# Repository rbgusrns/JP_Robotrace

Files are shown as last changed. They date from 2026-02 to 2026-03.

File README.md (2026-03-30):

<div align="center">

# JP_Robotrace
### Competition-grade line tracing robot platform

A complete robot tracing project that brings together firmware, electronics, and mechanical design in one repository.

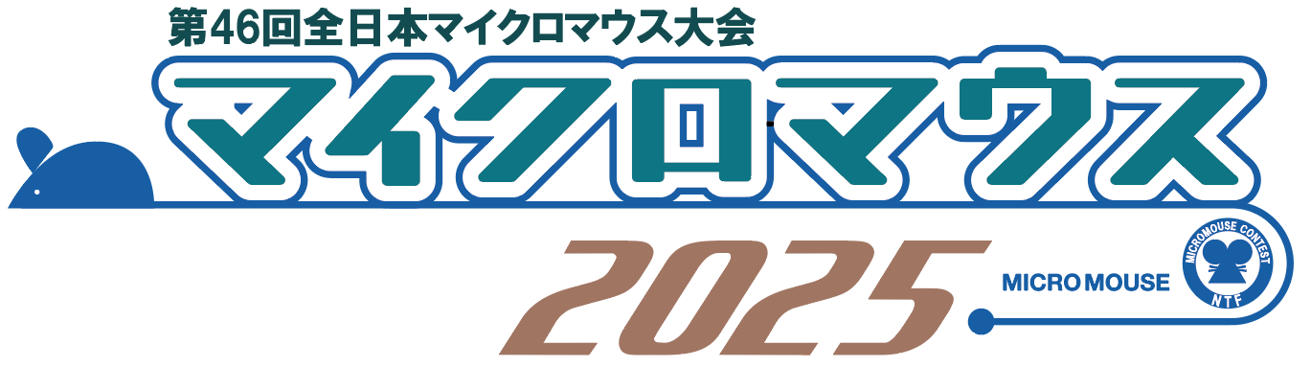
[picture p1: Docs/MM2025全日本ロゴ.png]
MM2025 poster


<br />






</div>

---

## Overview

`JP_Robotrace` is a line tracing robot project built for high-speed autonomous racing. The repository does not only contain firmware. It also includes PCB design data, manufacturing outputs, mechanical assets, and component references, which makes it closer to a full robot platform archive than a source-only codebase.

At the center of the project is a TI C2000-based control system tuned for fast and stable line following, with dedicated run modes, sensor processing, motion control, and board-level hardware design captured together in one place.

---

## Competition Result

`JP_Robotrace` competed as `RT51` at MM2025 and finished in 8th place overall.

The official best record captured in the event result sheet is `0:13.074`, which makes this repository not just a development archive, but also a record of a robot that completed the competition with a top-10 finish.

<p align="center">
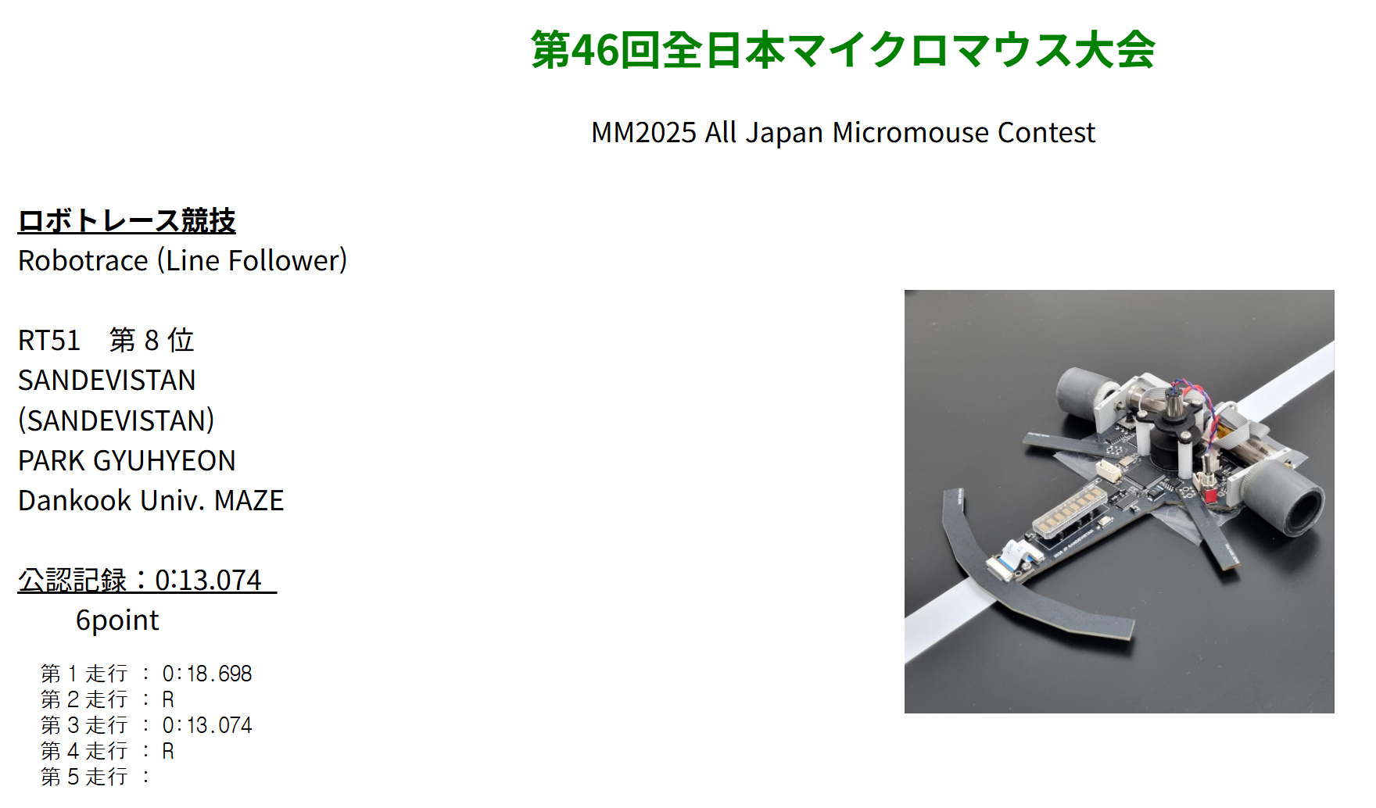
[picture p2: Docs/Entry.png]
MM2025 result sheet showing RT51 finishing 8th
  
</p>

<p align="center">
  <sub>MM2025 result sheet for RT51: finished 8th with an official best record of 0:13.074.</sub>
</p>

---

## Gallery

<table>
  <tr>
    <td width="50%">
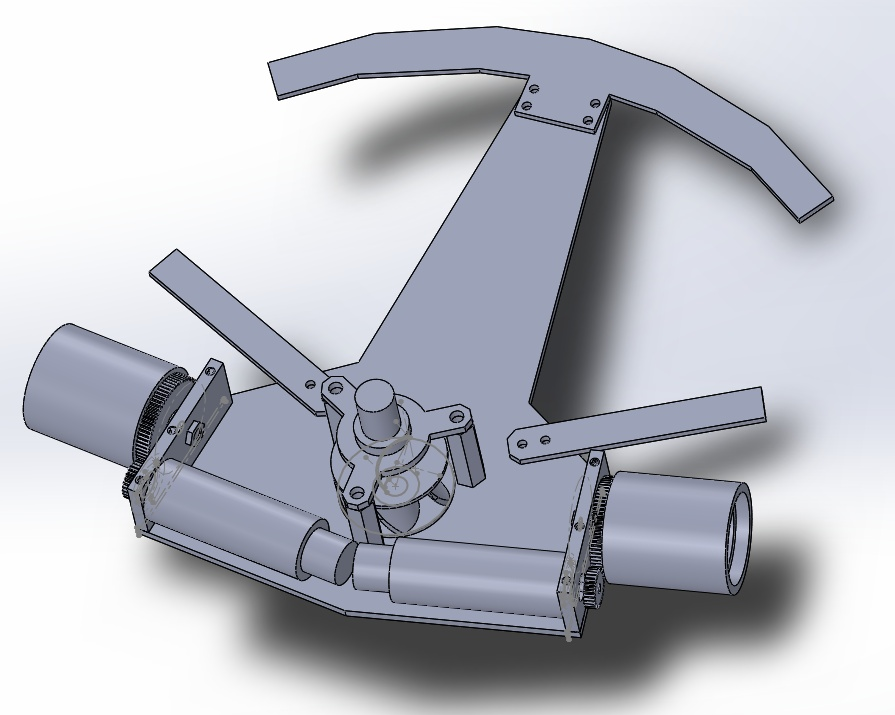
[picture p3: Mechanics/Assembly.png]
Assembly model
      
    </td>
    <td width="50%">
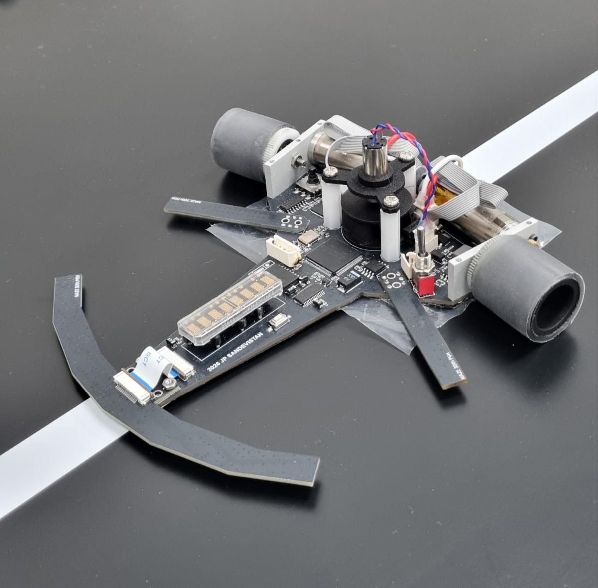
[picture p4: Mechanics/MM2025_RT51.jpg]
Robot photo
      
    </td>
  </tr>
  <tr>
    <td width="50%">
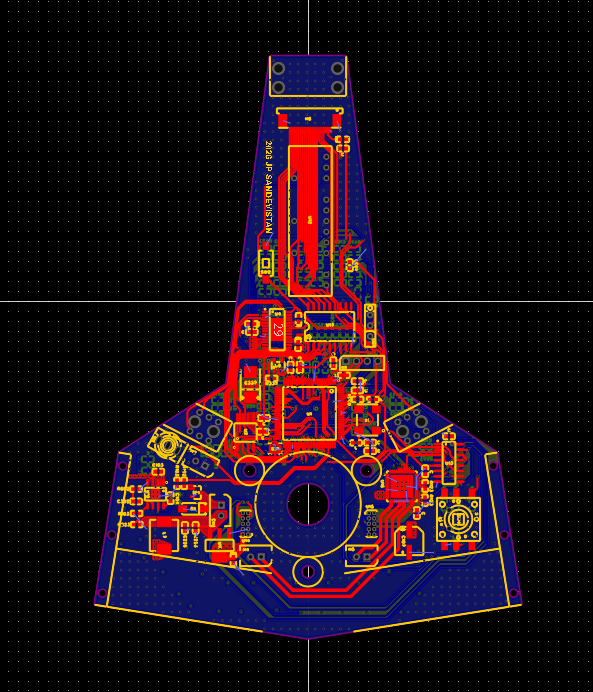
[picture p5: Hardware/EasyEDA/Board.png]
Main board
      
    </td>
    <td width="50%">
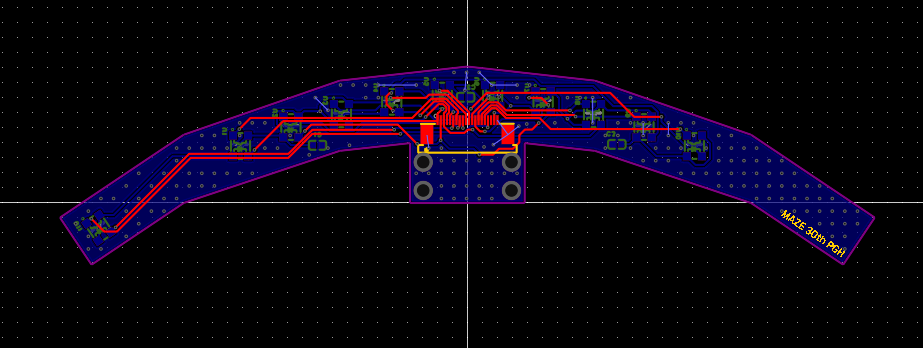
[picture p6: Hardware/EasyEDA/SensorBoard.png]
Sensor board
      
    </td>
  </tr>
</table>

<p align="center">
  <sub>Event identity, mechanical design, real hardware, and board-level engineering all live in the same archive.</sub>
</p>

---

## Key Features

- High-speed line tracing firmware for competitive robot racing
- Multiple driving modes including search, fast run, extreme run, and bril run
- Closed-loop motion control using encoder and sensor feedback
- Dedicated modules for motor control, gyro handling, flash, menu, and display
- Hardware resources including EasyEDA projects and production Gerber files
- Mechanical assets including STEP models and assembled robot visuals

---

## Project Structure

```text
JP_Robotrace/
├── Docs/                    # Component documents and technical references
├── Hardware/                # PCB design files, Gerbers, and logic references
│   ├── EasyEDA/
│   ├── Gerber/
│   └── Logic/
├── Mechanics/               # Mechanical assets, photos, and STEP models
│   └── STEP/
└── Software/                # Embedded firmware source and toolchain files
    ├── Compiler/
    ├── include/
    └── main/
```

---

## Software Layout

The embedded source is centered in `Software/main/`, where the project is split by function instead of by abstraction-heavy layers. Important files include:

- `main.c` - system initialization and core runtime setup
- `Motor.c` - motor control logic
- `Sensor.c` - sensor processing for line detection
- `gyro.c` - gyro interface and related handling
- `Search.c` - search-oriented run logic
- `Fastrun.c` - faster race mode logic
- `Extremerun.c` - aggressive run profile
- `brilrun.c` - high-performance run mode
- `Menu.c` - local interface and configuration flow
- `flash.c` - flash memory handling
- `VFD.c` - display output control

The source was written with Source Insight as the editing environment, and the shipped `Software/main/MAKEFILE` identifies the output target as `a_ZILLIIAX` while referencing a TI C2000-oriented IAR build chain and supporting libraries.

---

## Hardware

This repository also preserves the electrical side of the robot.

- `Hardware/EasyEDA/` contains editable PCB project files and preview images
- `Hardware/Gerber/` contains manufacturing-ready archives for the boards
- `Hardware/Logic/` contains supporting circuit reference documents

---

## Mechanical Assets

The `Mechanics/` directory includes both presentation assets and 3D geometry.

- `Assembly.png` shows the assembled system
- `MM2025_RT51.jpg` captures the robot in a real-world setting
- `STEP/` stores mechanical models such as wheel, gear, tire, and assembly data

That combination makes the repository useful not only for firmware study, but also for reconstructing the full build context of the robot.

---

## Technology Snapshot

| Category | Details |
|---|---|
| MCU | Texas Instruments `TMS320F2808` |
| Firmware Language | `C`, `Assembly` |
| Editor | Source Insight |
| Build Configuration | TI C2000 / IAR-oriented make flow |
| Build Target | `a_ZILLIIAX` |
| Repository Scope | Firmware, PCB, Gerber, STEP, reference docs |

---

## Run Modes

Based on the source layout, the project includes several driving strategies with separate implementations:

- **Search** for controlled exploration and line acquisition
- **Fast Run** for higher-speed tracing
- **Extreme Run** for more aggressive motion profiles
- **Bril Run** for a top-end performance-oriented mode

This mode separation suggests a workflow that balances stability, route understanding, and maximum race pace.

---

## Build Notes

The repository contains source and make configuration, but it does not yet provide a polished step-by-step setup guide.

What can be verified from the repository:

- The firmware is built around a TI C2000 target
- The codebase was written with Source Insight as the editing environment
- `Software/main/MAKEFILE` references the IAR C2000 compiler, assembler, and linker
- The output target name is `a_ZILLIIAX`

What is still undocumented:

- Exact flashing procedure
- Required debugger or programmer hardware
- Board assembly and bring-up sequence
- Parameter tuning procedure for different tracks

---

## Why This Repository Is Interesting

Many robot repositories show only one slice of the work. `JP_Robotrace` is interesting because it keeps the full engineering story together: embedded control, electronics, manufacturing data, and mechanical design.

For anyone studying line tracing robots, embedded control systems, or complete competition robot workflows, this repository is a compact snapshot of how those disciplines come together in practice.

---

## Credits

From the project make configuration:

- **Author:** Yuk Keun Ho
- **Company:** MAZE

---

## License

This project is released under the `MIT` License. See `LICENSE` for details.

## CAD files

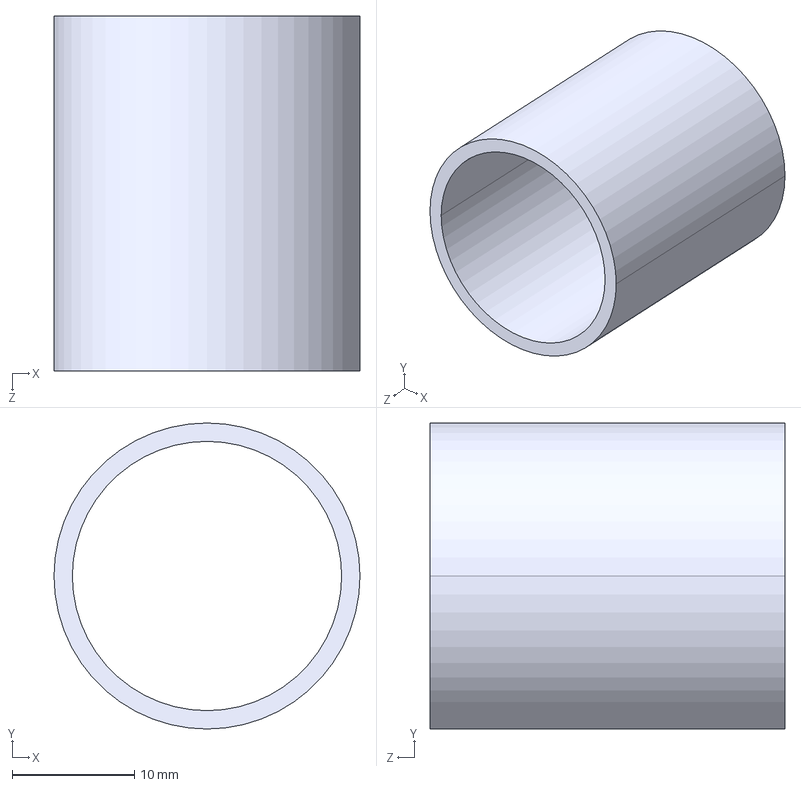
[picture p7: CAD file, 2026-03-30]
Mechanics/STEP/TIRE_OUT.STEP
25.0 x 25.0 x 29.0 mm

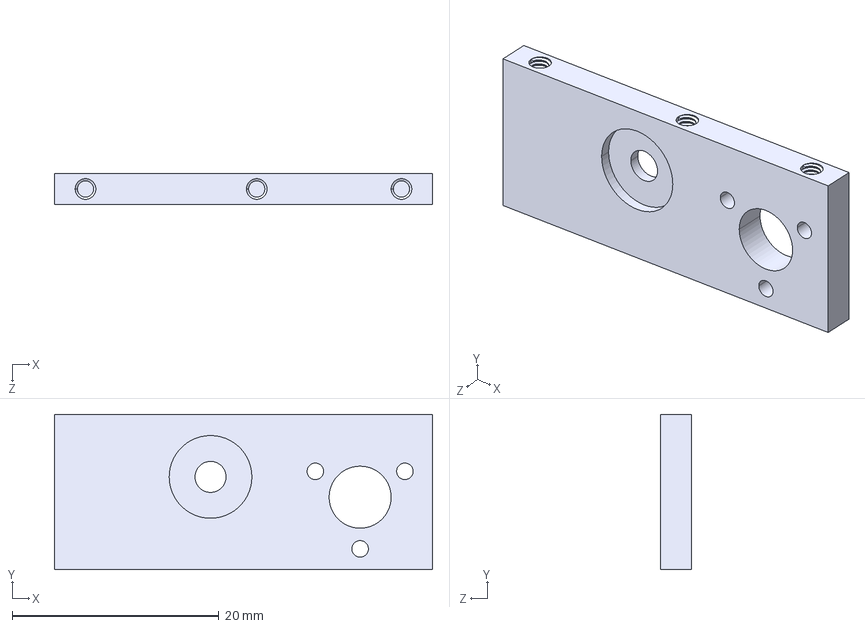
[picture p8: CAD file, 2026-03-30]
Mechanics/STEP/MTG_L.STEP
36.6 x 15.0 x 3.00 mm

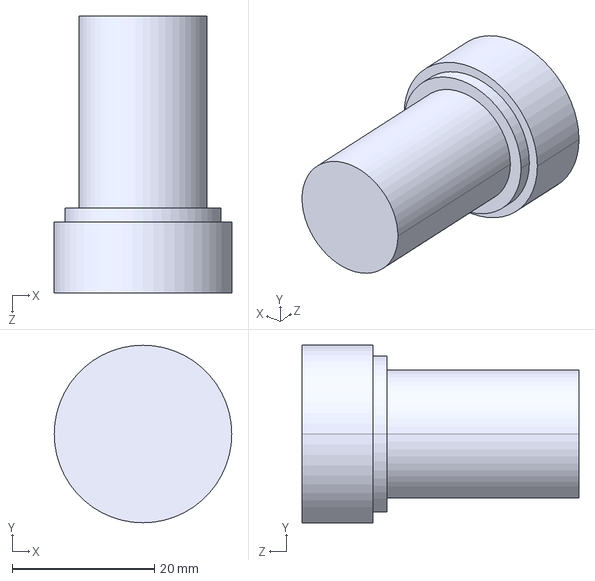
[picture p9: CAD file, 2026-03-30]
Mechanics/STEP/TIRE_IN.STEP
25.0 x 25.0 x 39.0 mm

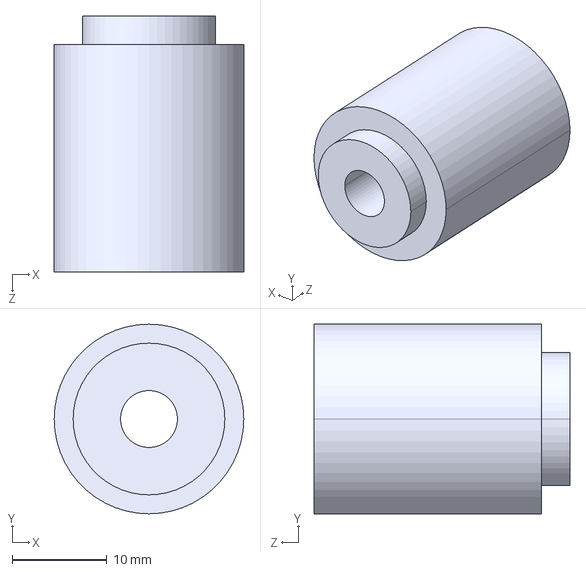
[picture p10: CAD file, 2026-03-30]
Mechanics/STEP/WHEEL.STEP
20.0 x 20.0 x 27.0 mm

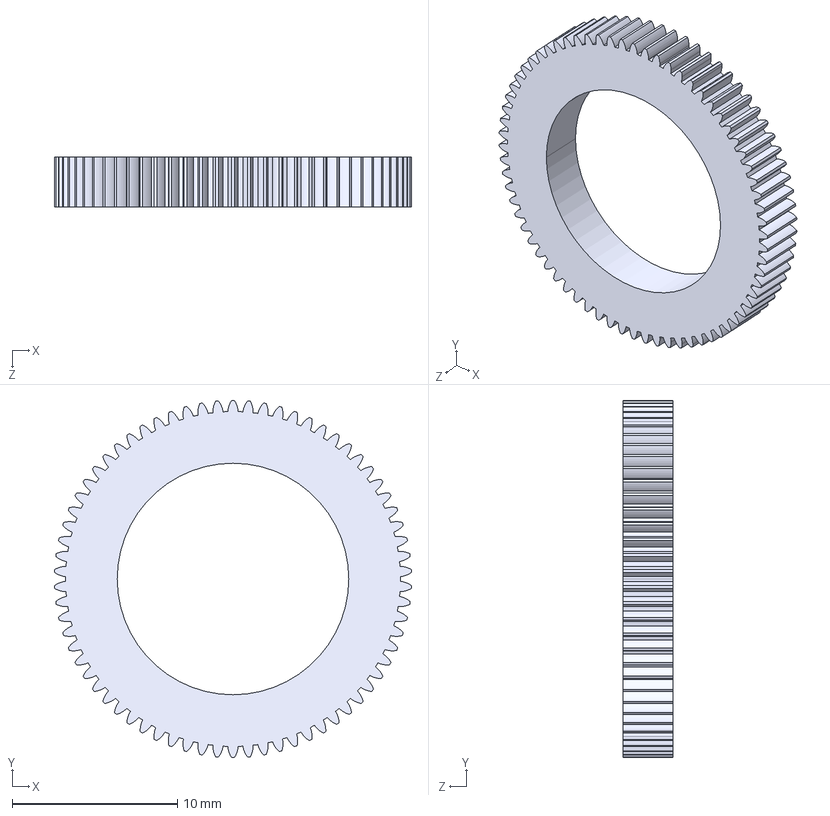
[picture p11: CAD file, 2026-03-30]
Mechanics/STEP/GEAR.STEP
21.6 x 21.6 x 3.00 mm

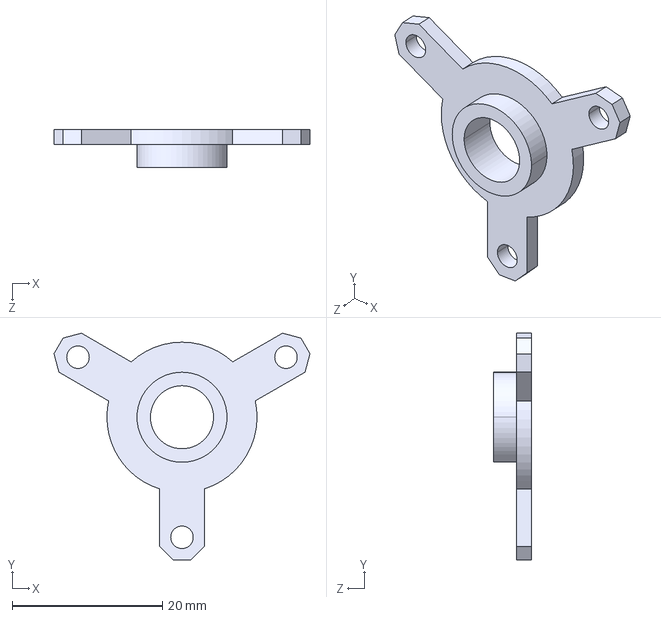
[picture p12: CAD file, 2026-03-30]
Mechanics/STEP/SUCTION_FIX.STEP
34.1 x 30.2 x 5.00 mm

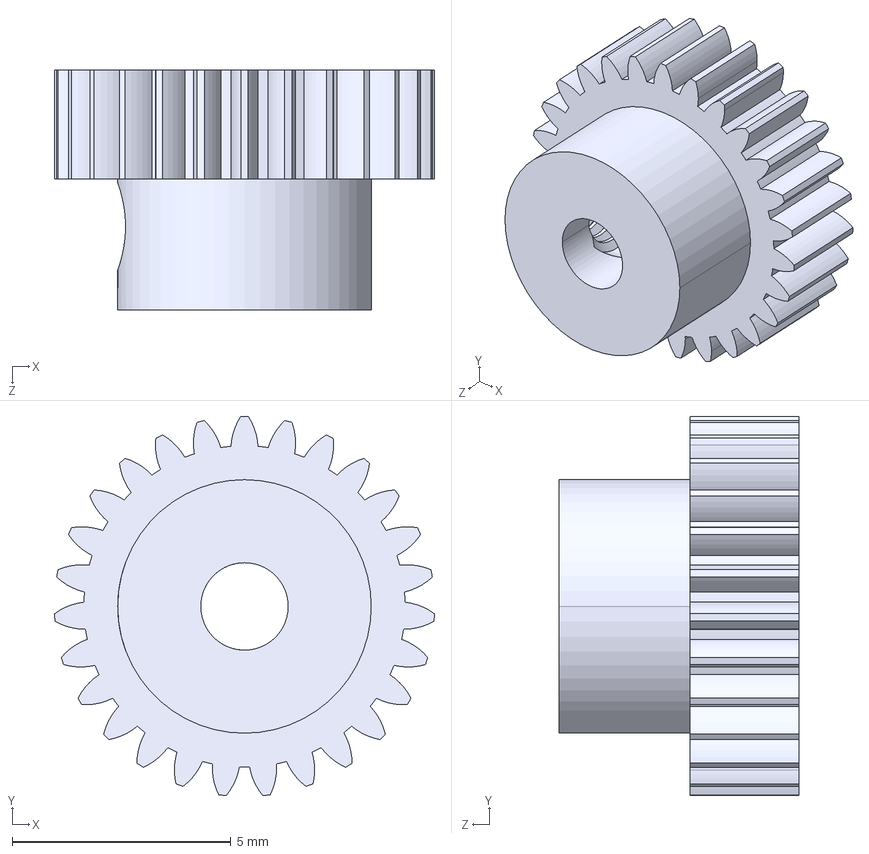
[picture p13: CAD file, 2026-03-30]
Mechanics/STEP/PINION.STEP
8.69 x 8.68 x 5.50 mm

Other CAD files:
Software/main/main.obj
Software/main/Rom.obj
Software/main/DSP280x_DefaultIsr.obj
Mechanics/STEP/JP_MTG_R.STEP
Software/main/DSP280x_EPwm.obj
Software/main/VFD.obj
Software/main/sensor.obj
Mechanics/STEP/JP_MTG_L.STEP
Software/main/DSP280x_PieCtrl.obj
Software/main/DSP280x_Gpio.obj
Software/main/fastrun.obj
Mechanics/STEP/MTG_R.STEP
Mechanics/STEP/SUCTION.STEP
Software/main/DSP280x_Adc.obj
Software/main/DSP280x_CodeStartBranch.obj
Software/main/DSP280x_CpuTimers.obj
Software/main/DSP280x_EQep.obj
Software/main/DSP280x_GlobalVariableDefs.obj
Software/main/DSP280x_MemCopy.obj
Software/main/DSP280x_PieVect.obj
Software/main/DSP280x_Sci.obj
Software/main/DSP280x_Spi.obj
Software/main/DSP280x_SysCtrl.obj
Software/main/DSP280x_usDelay.obj
Software/main/Motor.obj
Software/main/brilrun.obj
Software/main/extremerun.obj
Software/main/gyro.obj
Software/main/menu.obj
Software/main/search.obj

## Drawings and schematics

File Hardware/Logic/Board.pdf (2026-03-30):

GPIO4/EPWM3A 51 GPIO17/SPISOMIA/CANRXB/TZ6# 52 GPIO5/EPWM3B/SPICLKD/ECAP1 53 GPIO18/SPICLKA/SCITXDB 54 VSS 55 GPIO6/EPWM4A/EPWMSYNCI/EPWMSYNCO 56 GPIO19/SPISTEA/SCIRXDB 57 GPIO7/EPWM4B/SPISTED/ECAP2 58 VDD 59 GPIO8/EPWM5A/CANTXB/ADCSOCAO# 60 GPIO9/EPWM5B/SCITXDB/ECAP3 61 VSS 62 GPIO20/EQEP1A/SPISIMOC/CANTXB 63 GPIO10/EPWM6A/CANRXB/ADCSOCBO# 64 VDDIO 65 XCLKOUT 66 GPIO21/EQEP1B/SPISOMIC/CANRXB 67 VDD 68 VSS 69 GPIO11/EPWM6B/SCIRXDB/ECAP4 70 GPIO22/EQEP1S/SPICLKC/SCITXDB 71 GPIO23/EQEP1I/SPISTEC/SCIRXDB 72 TDI 73 TMS 74 TCK 75 TDO ⁷⁶ VSS ⁷⁷ XRS# 78 GPIO²⁷/ECAP⁴/EQEP²S/SPISTEB ⁷⁹ EMU⁰ ⁸⁰ EMU¹ ⁸¹ VDDIO ⁸² GPIO²⁴/ECAP¹/EQEP²A/SPISIMOB ⁸³ TRST# 84 VDD ⁸⁵

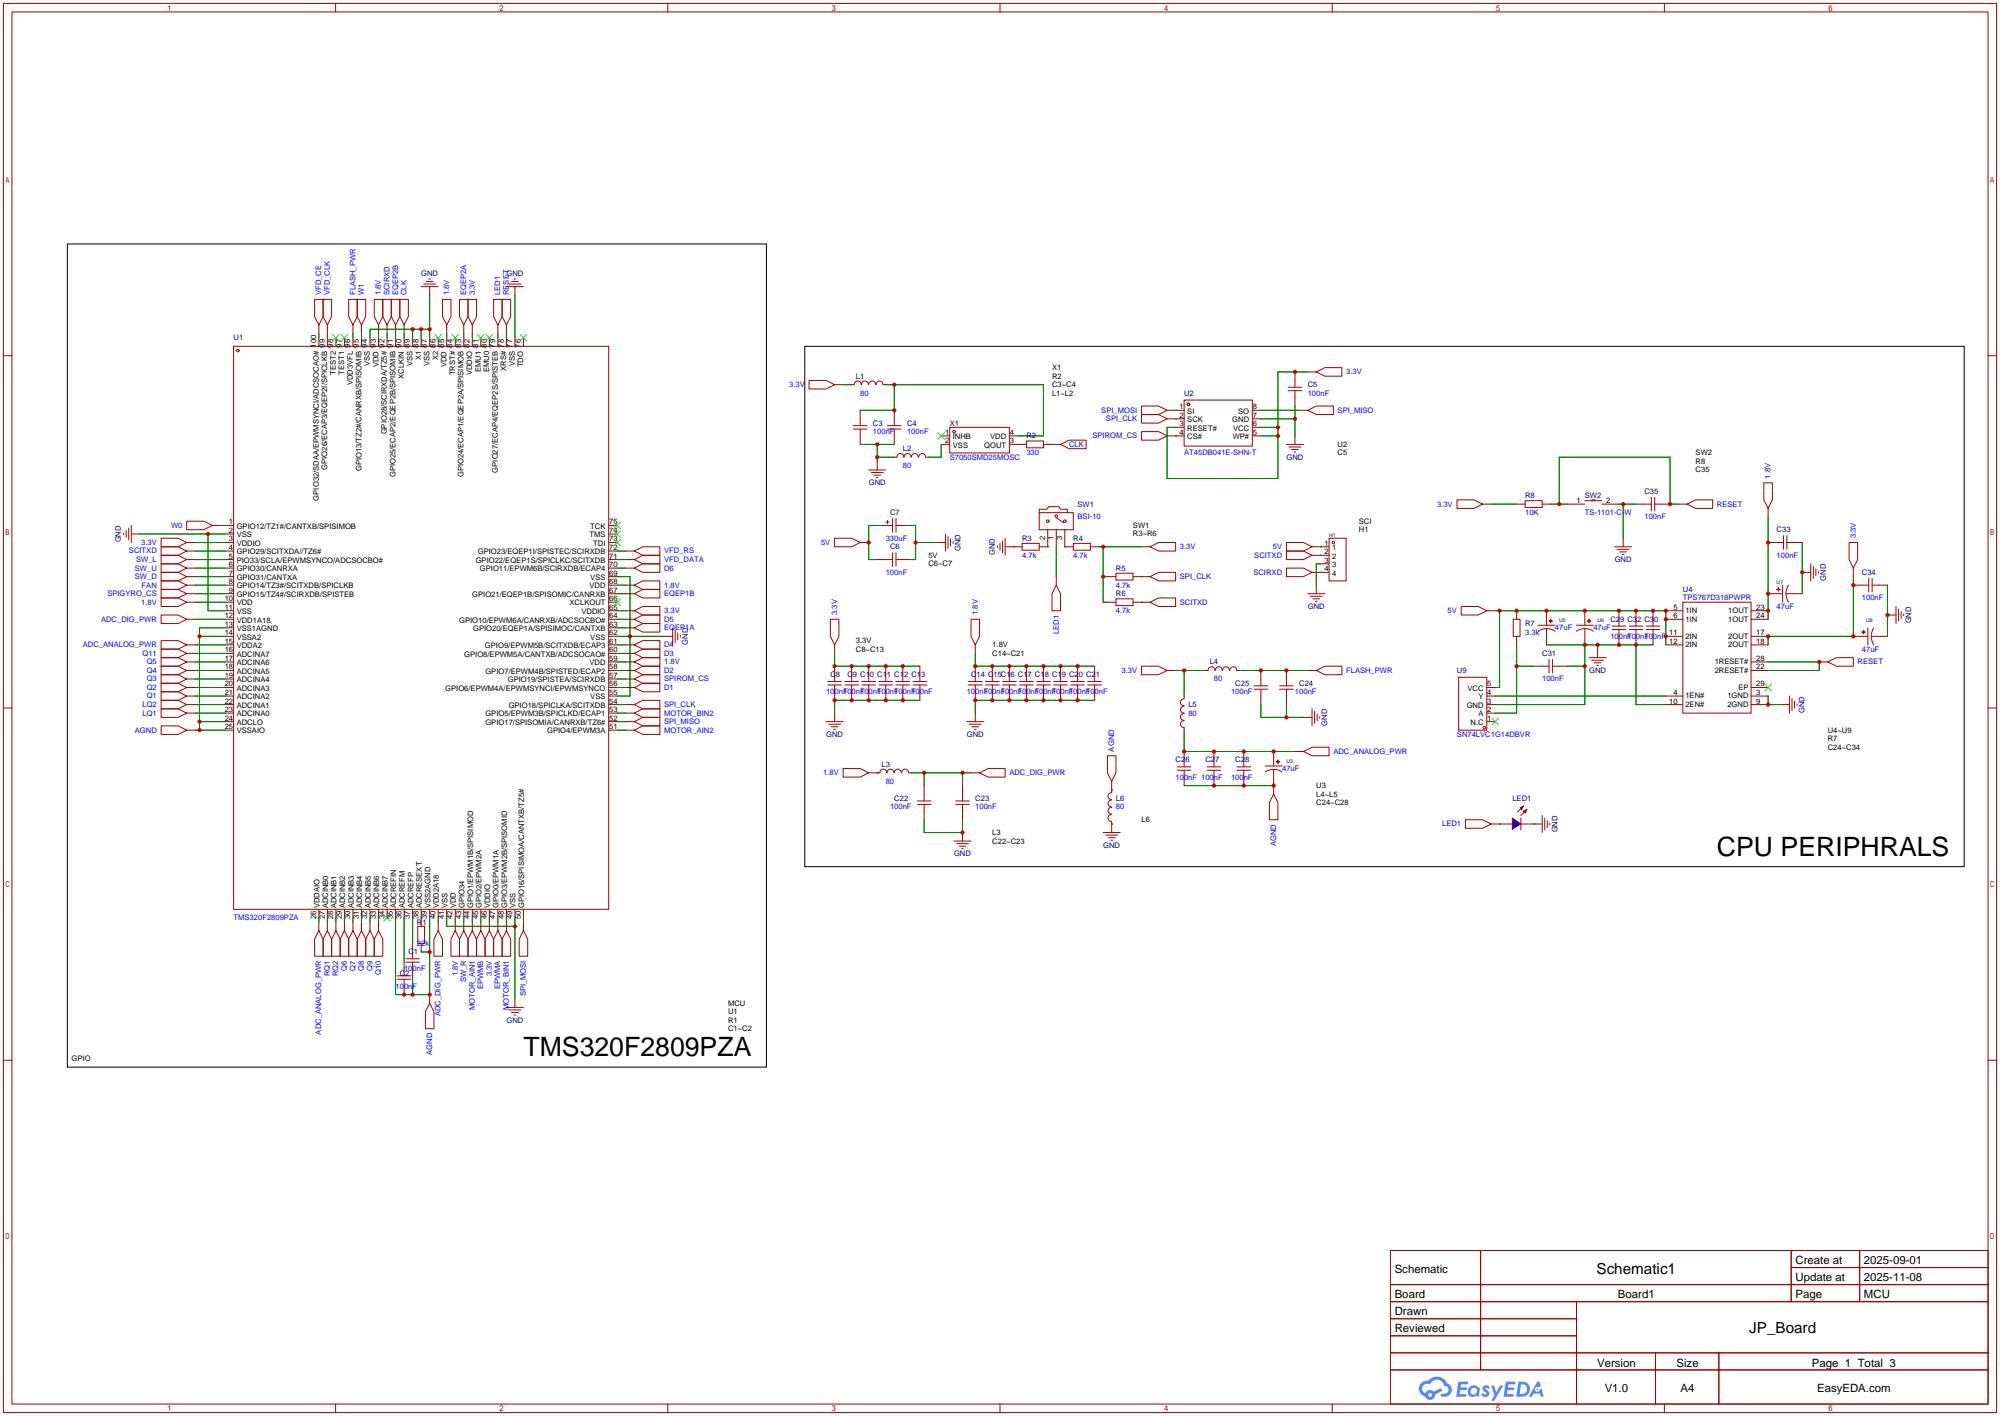
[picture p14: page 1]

Schematic | Schematic1 | Create at | 2025-09-01

Update at | 2025-11-08

Board | Board1 | Page | MCU
Drawn | | JP_Board
Reviewed

Version | Size | Page 1 Total 3
V1.0 | A4 | EasyEDA.com

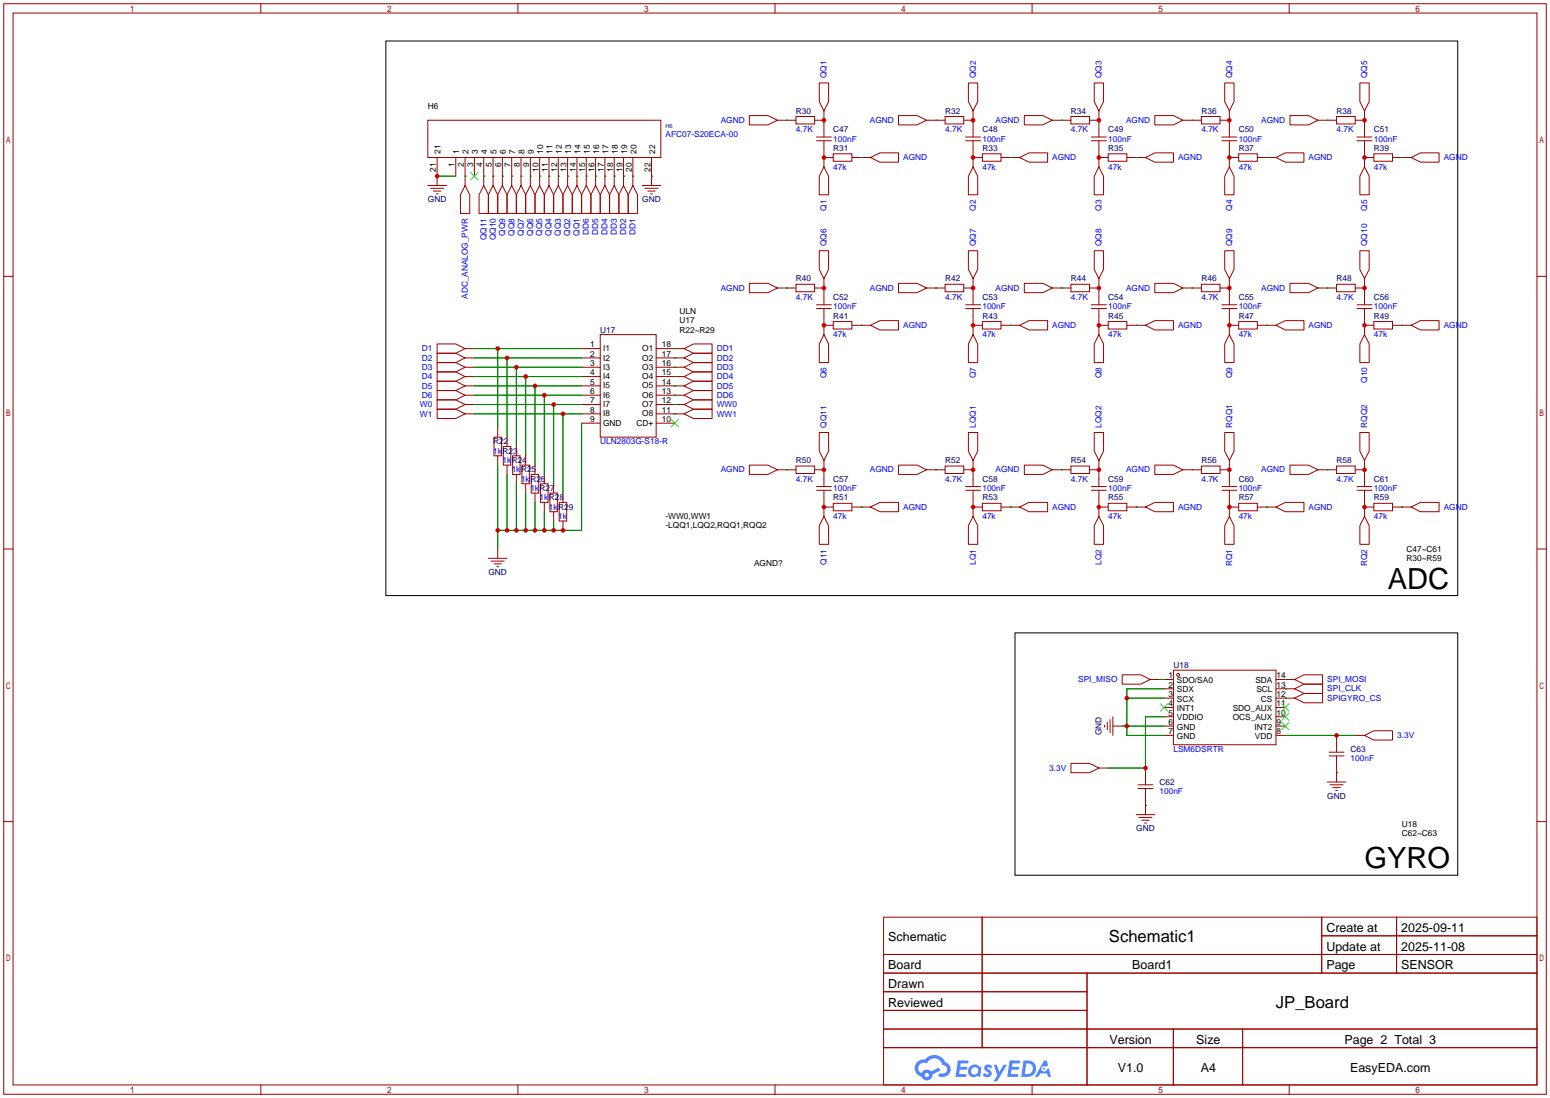
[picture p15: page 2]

Schematic | Schematic1 | Create at | 2025-09-11

Update at | 2025-11-08

Board | Board1 | Page | SENSOR
Drawn | | JP_Board
Reviewed

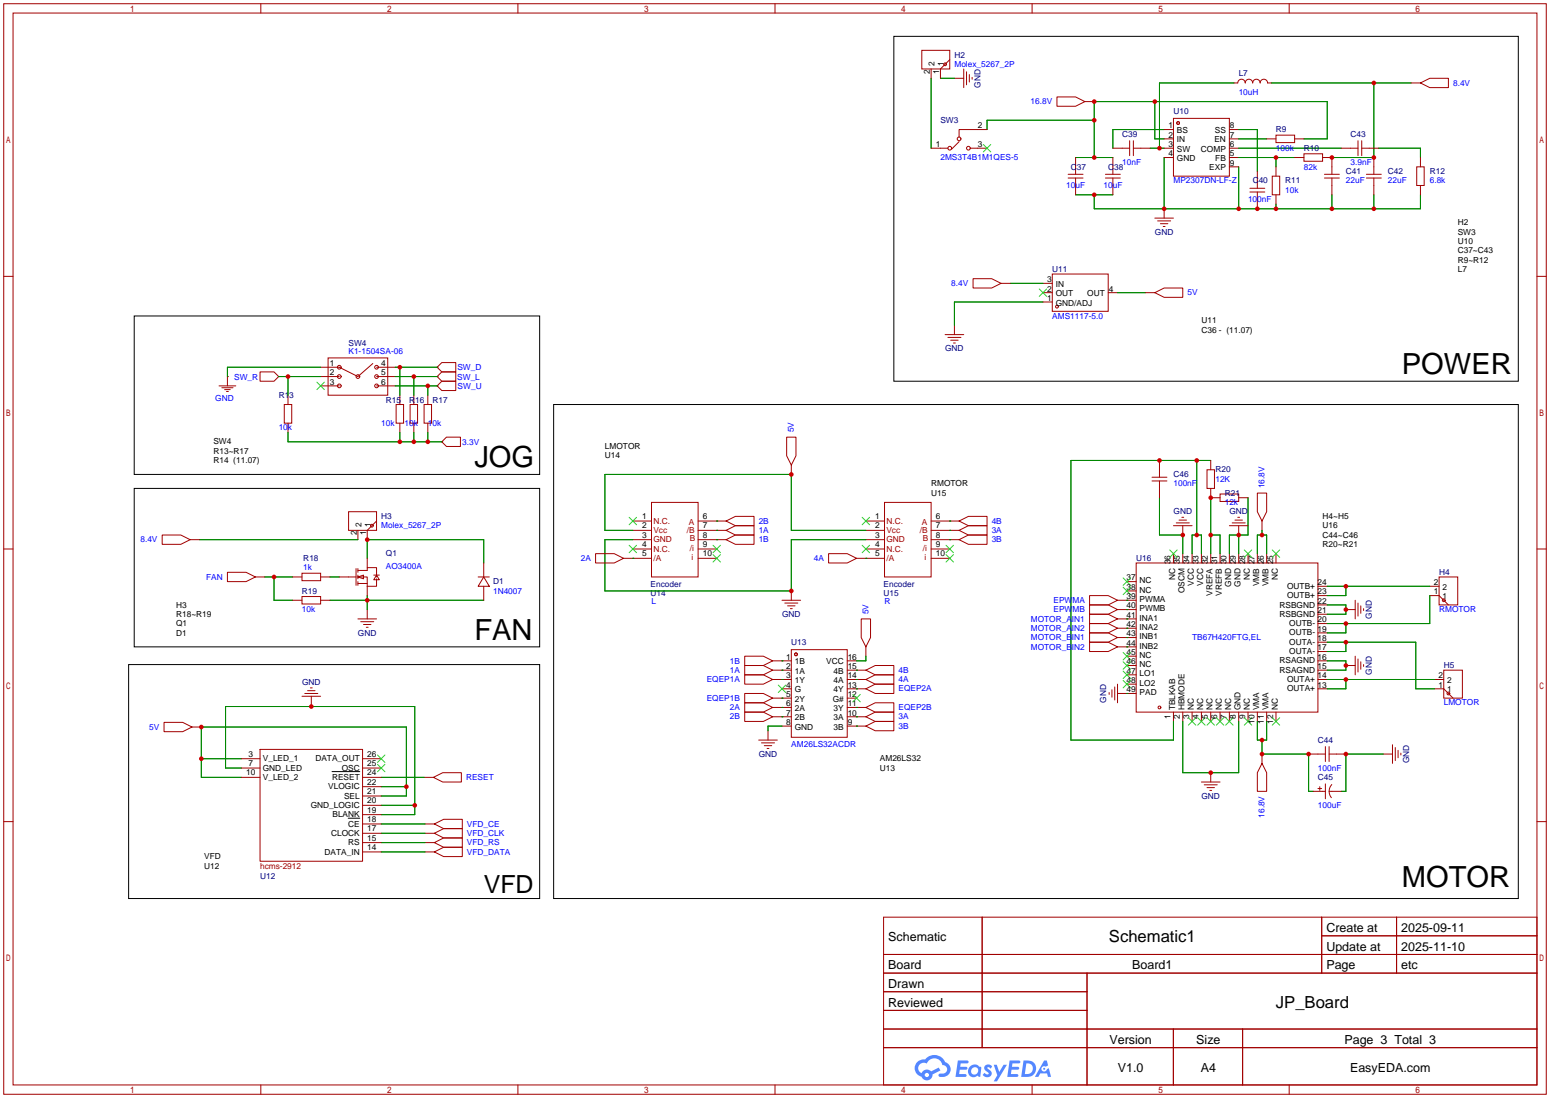
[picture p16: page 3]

NC 25 VMB 26 VMB 27 NC 28 GND 29 GND 30 VREFB 31 VREFA 32 VCC 33 VCC 34 OSCM 35 NC 36

DATA_IN 14 RS 15 CLOCK 17 CE 18 BLANK 19 GND_LOGIC 20 SEL 21 VLOGIC 22 RESET 24 OSC 25 DATA_OUT 26

Schematic | Schematic1 | Create at | 2025-09-11

Update at | 2025-11-10

Board | Board1 | Page | etc
Drawn | | JP_Board
Reviewed

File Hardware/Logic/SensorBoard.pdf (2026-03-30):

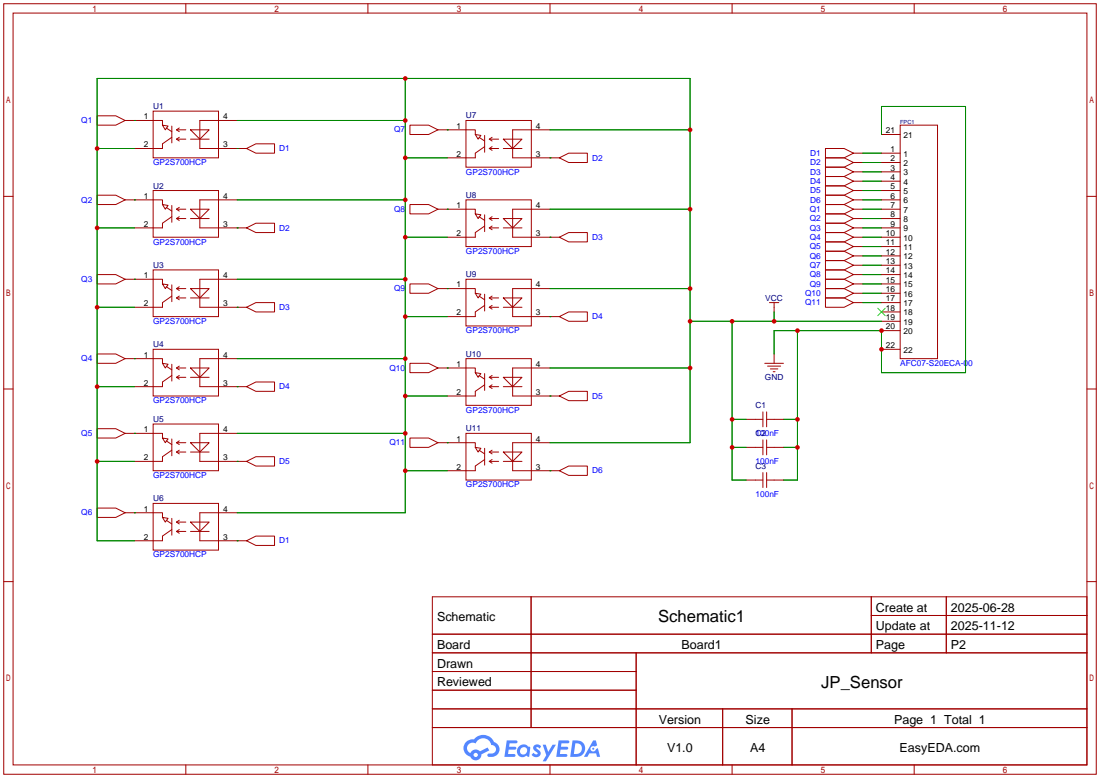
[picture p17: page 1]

Schematic | Schematic1 | Create at | 2025-06-28

Update at | 2025-11-12

Board | Board1 | Page | P2
Drawn | | JP_Sensor
Reviewed

Version | Size | Page 1 Total 1
V1.0 | A4 | EasyEDA.com

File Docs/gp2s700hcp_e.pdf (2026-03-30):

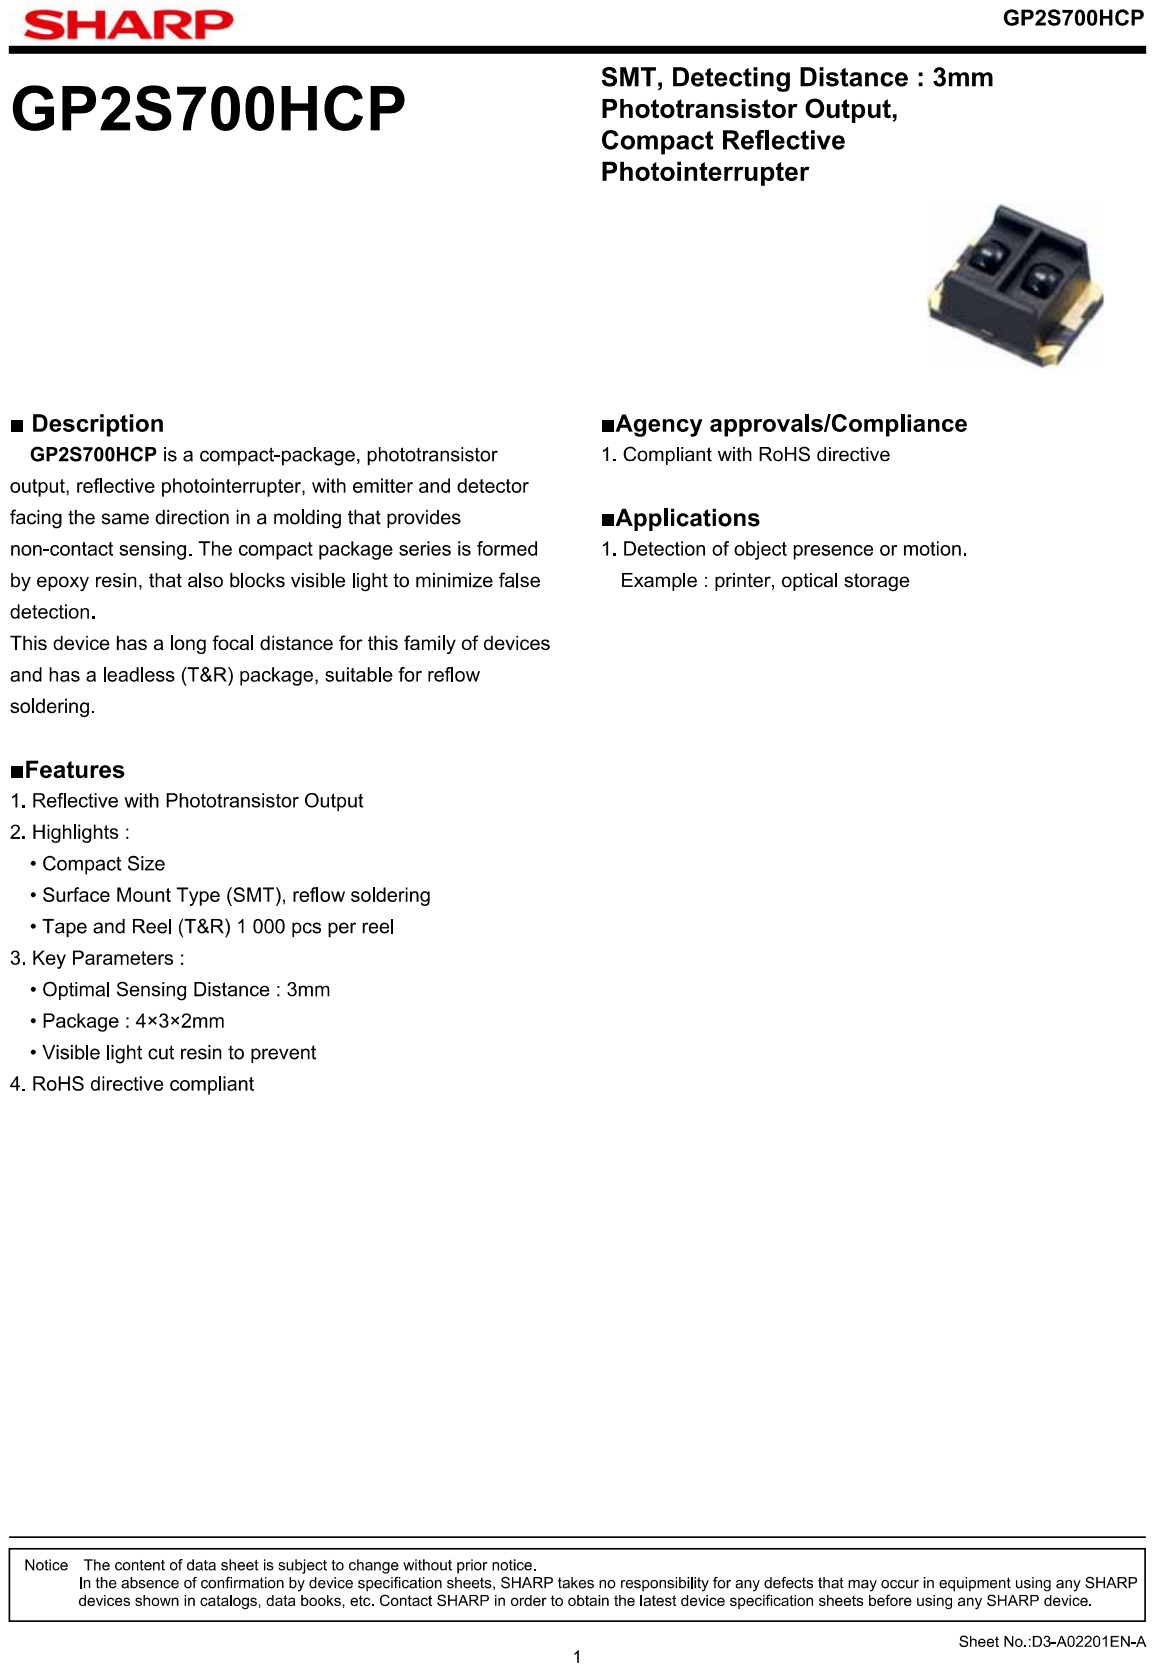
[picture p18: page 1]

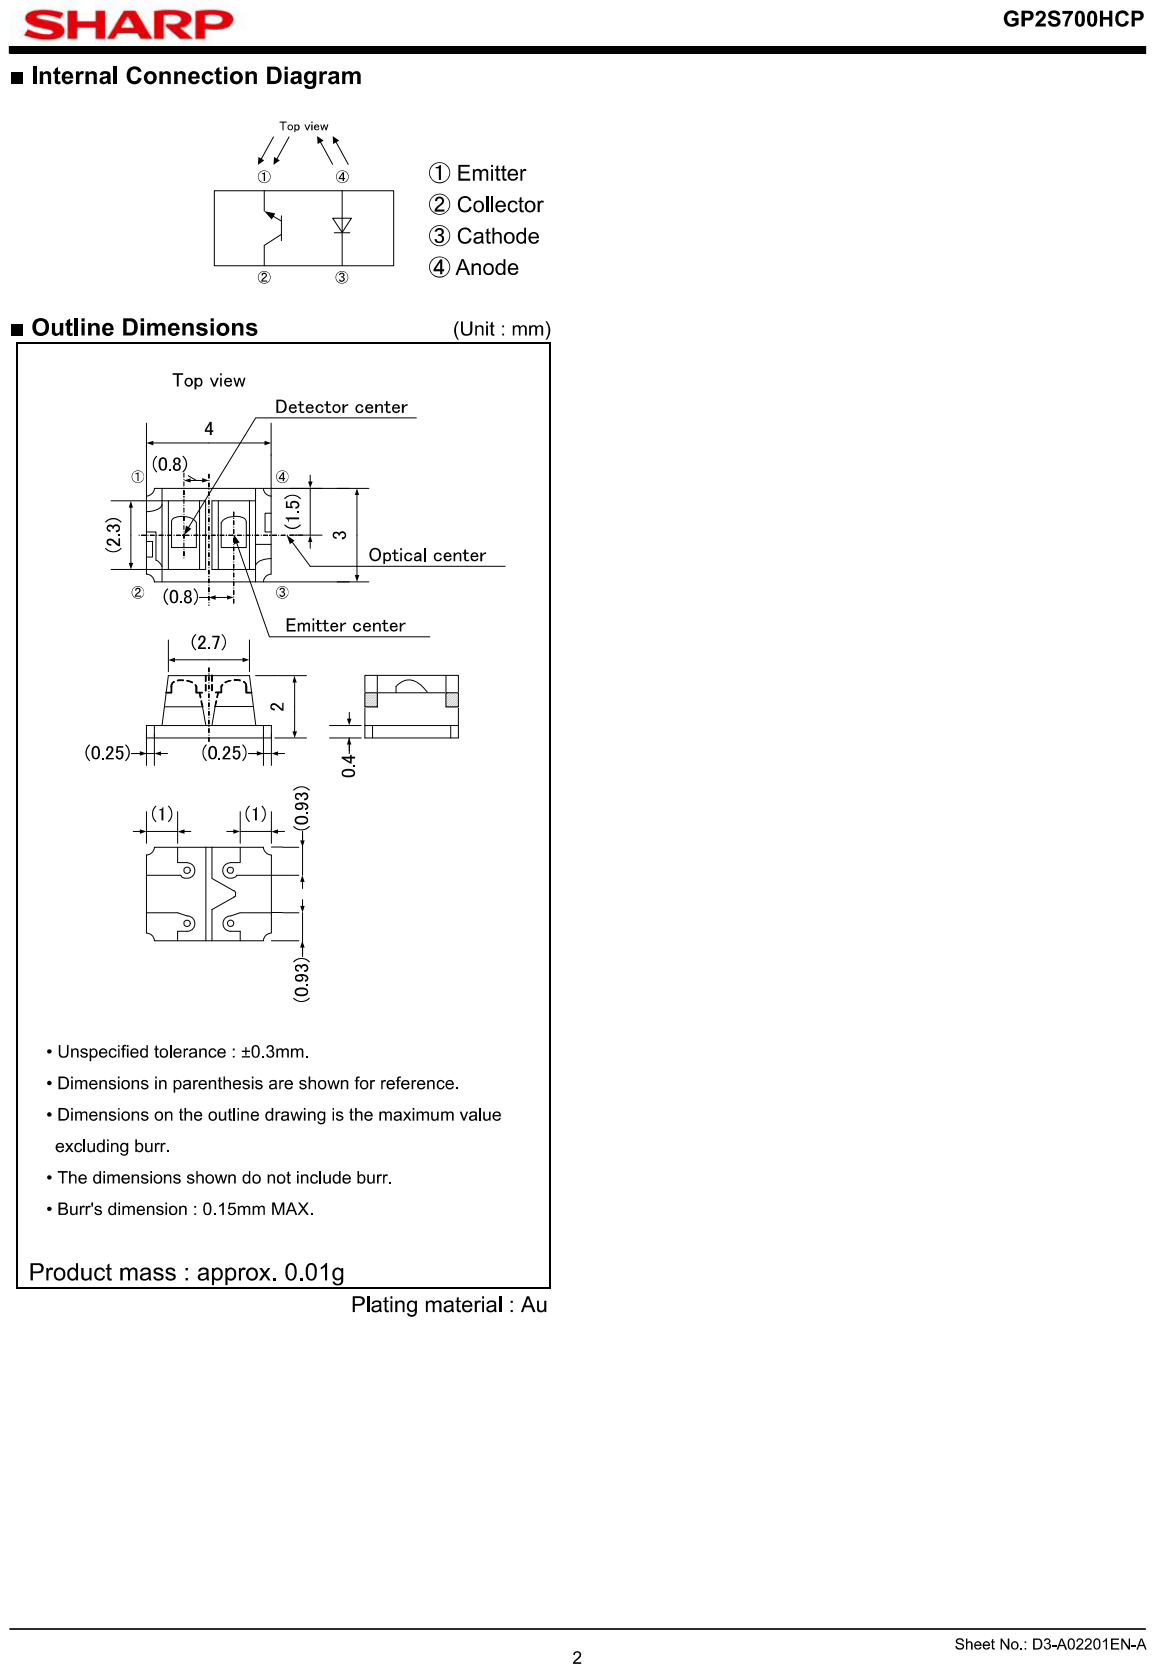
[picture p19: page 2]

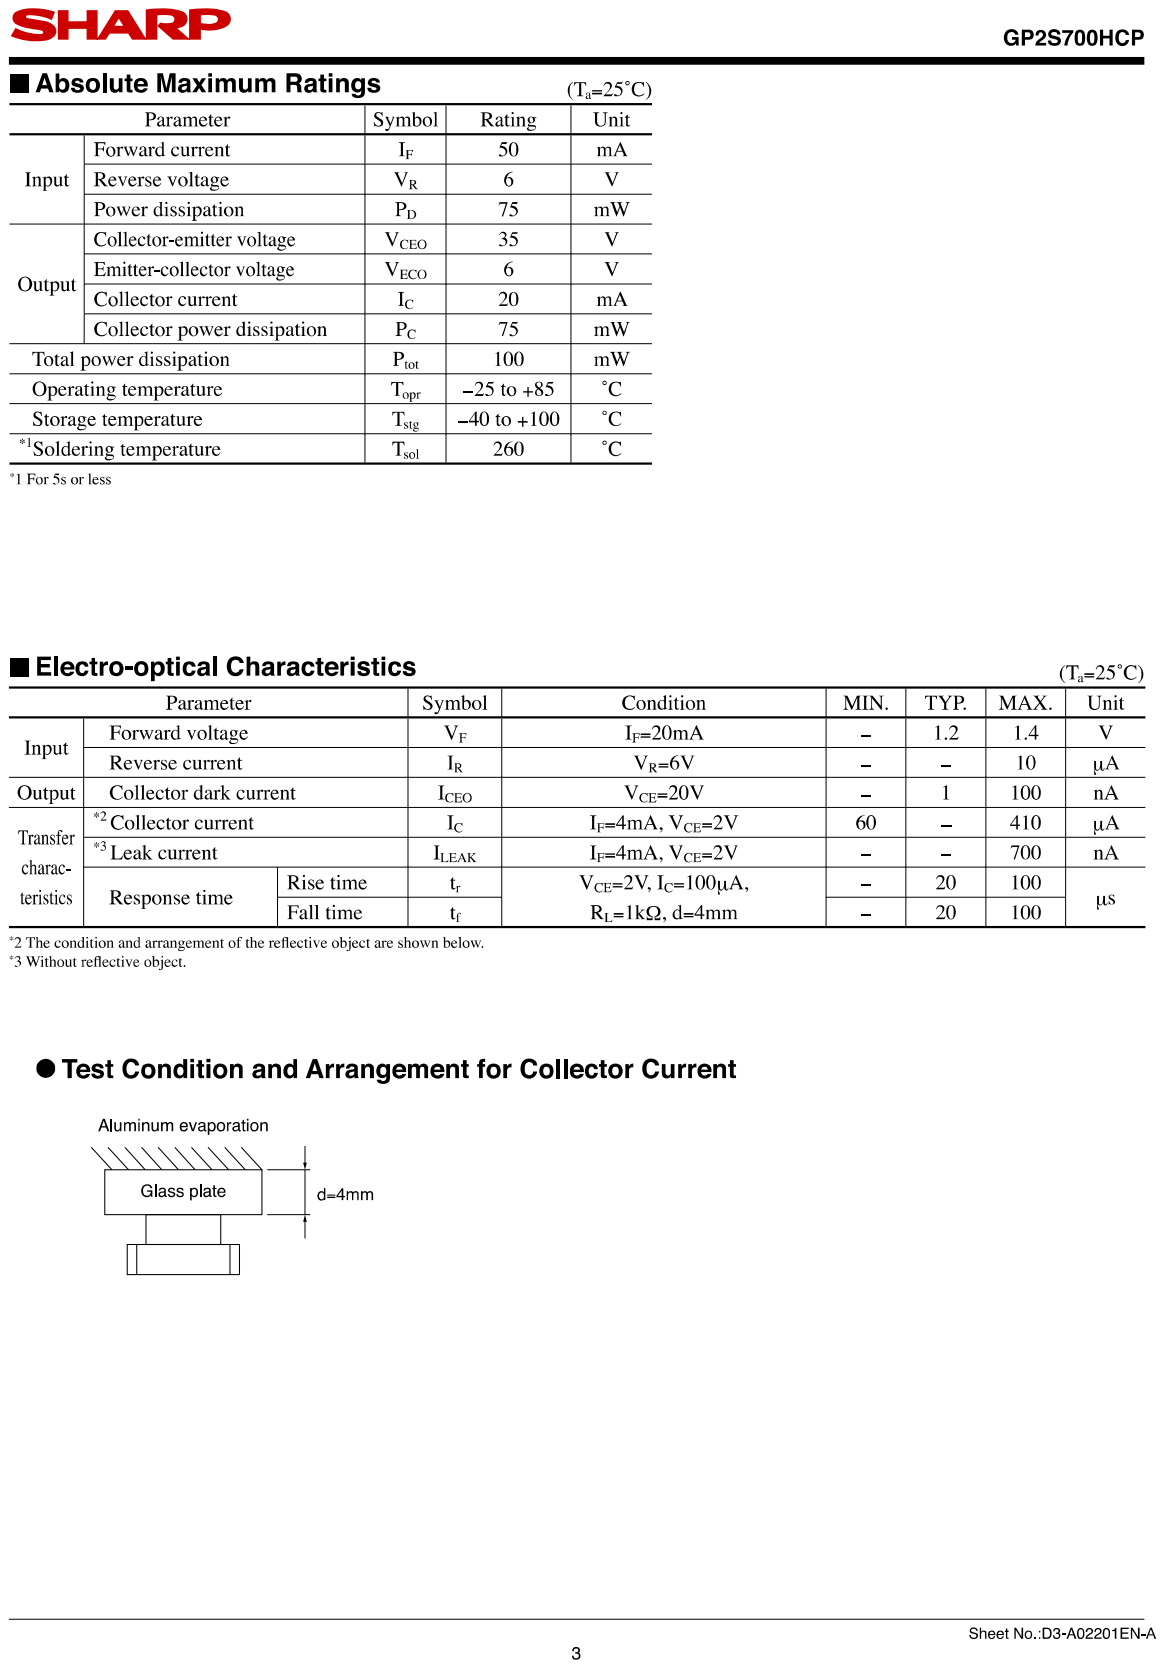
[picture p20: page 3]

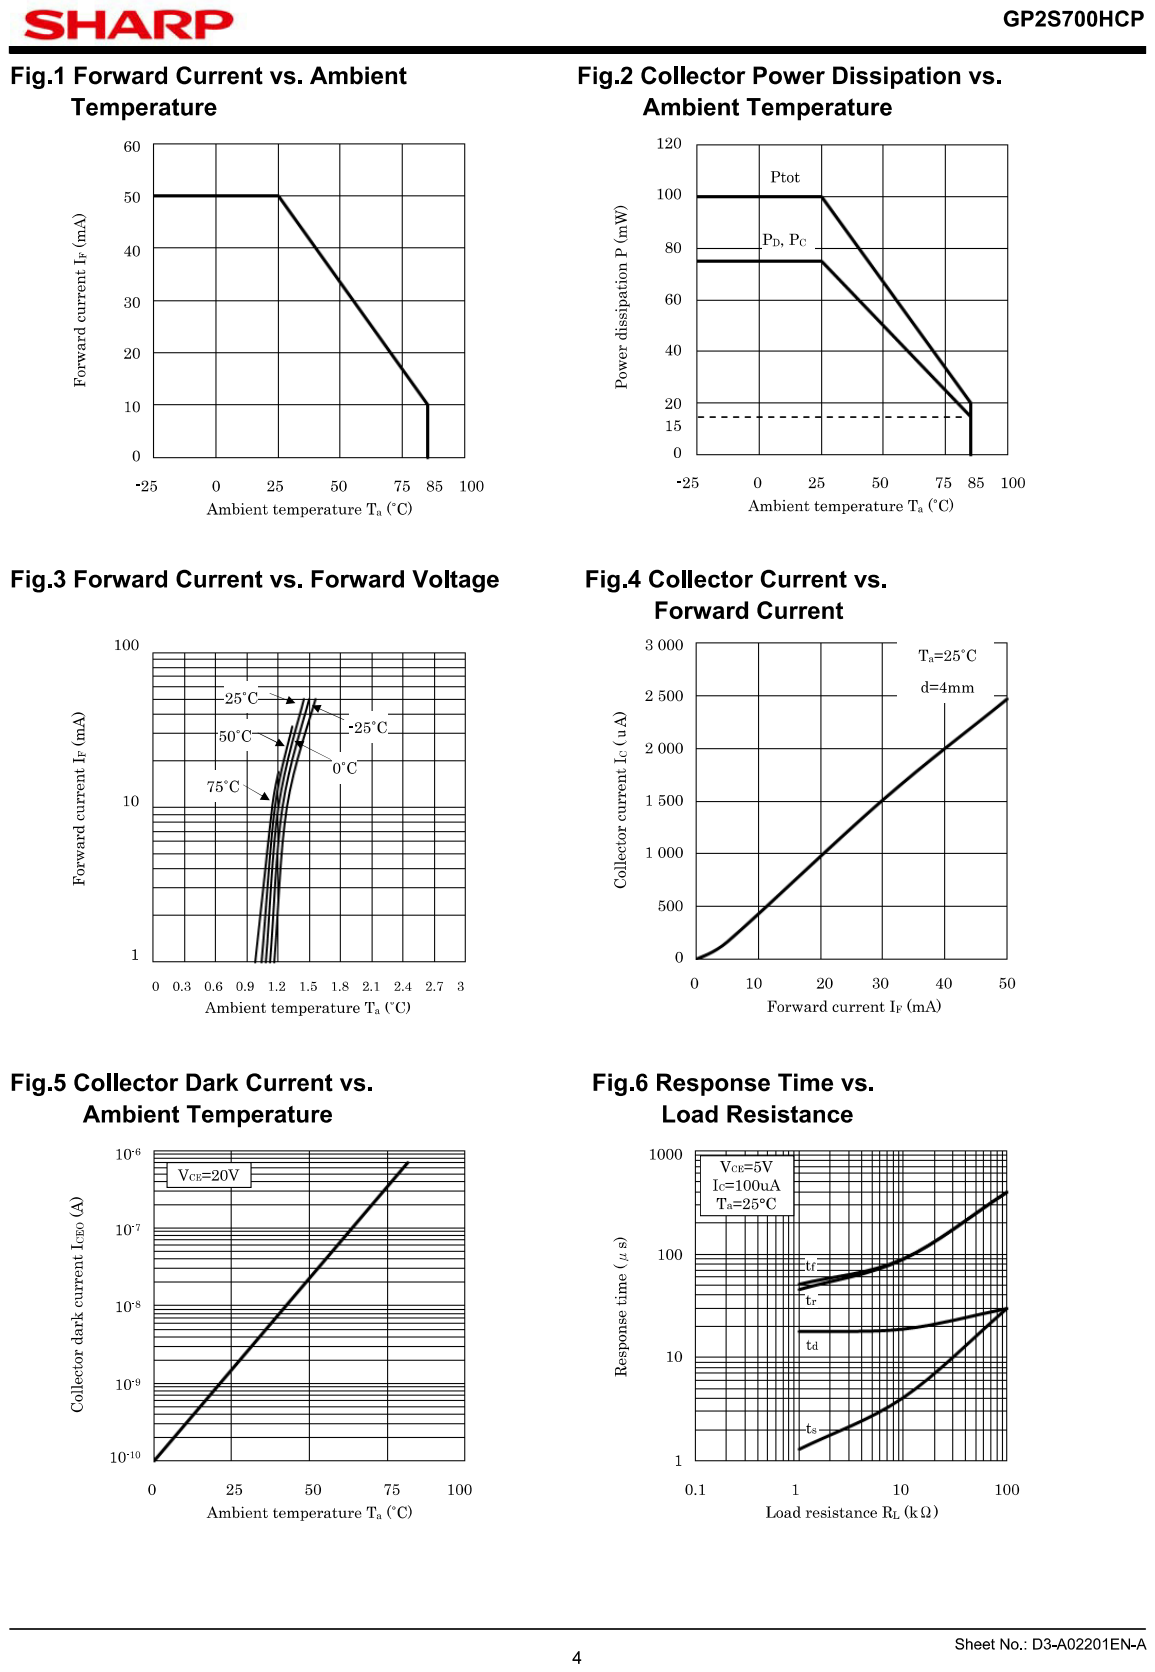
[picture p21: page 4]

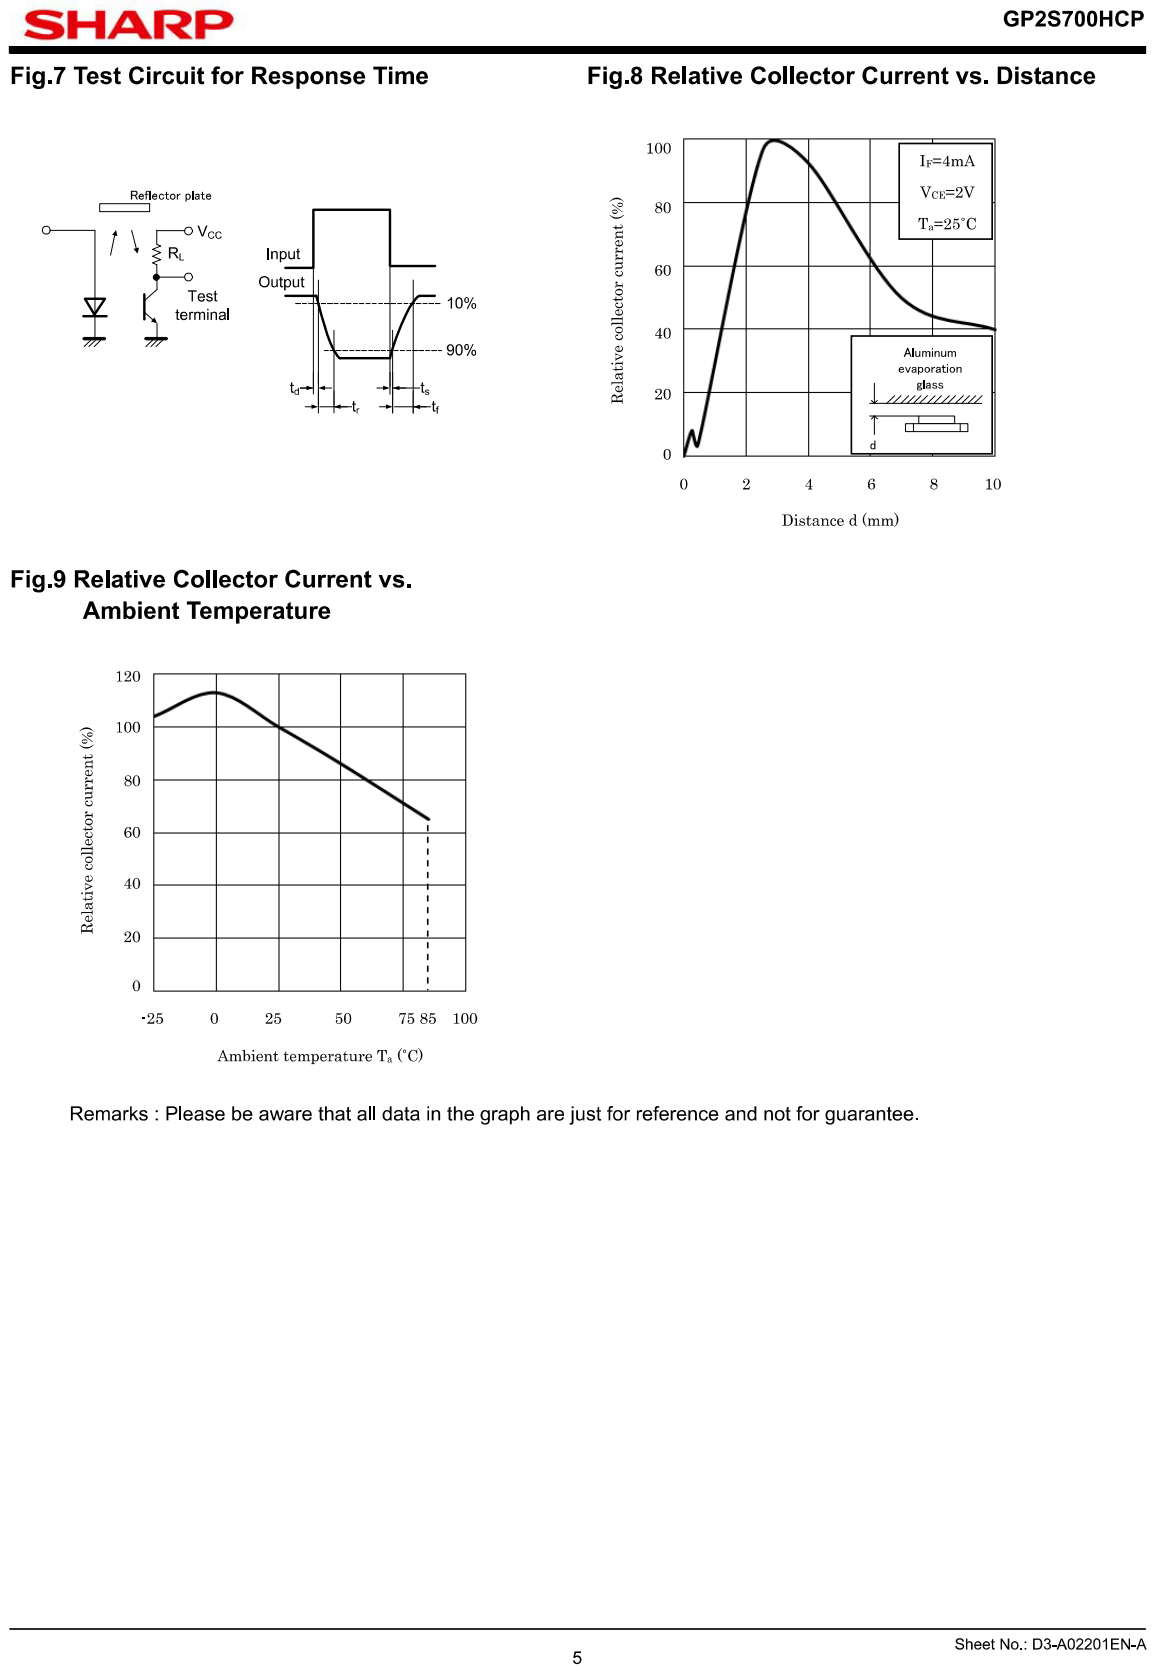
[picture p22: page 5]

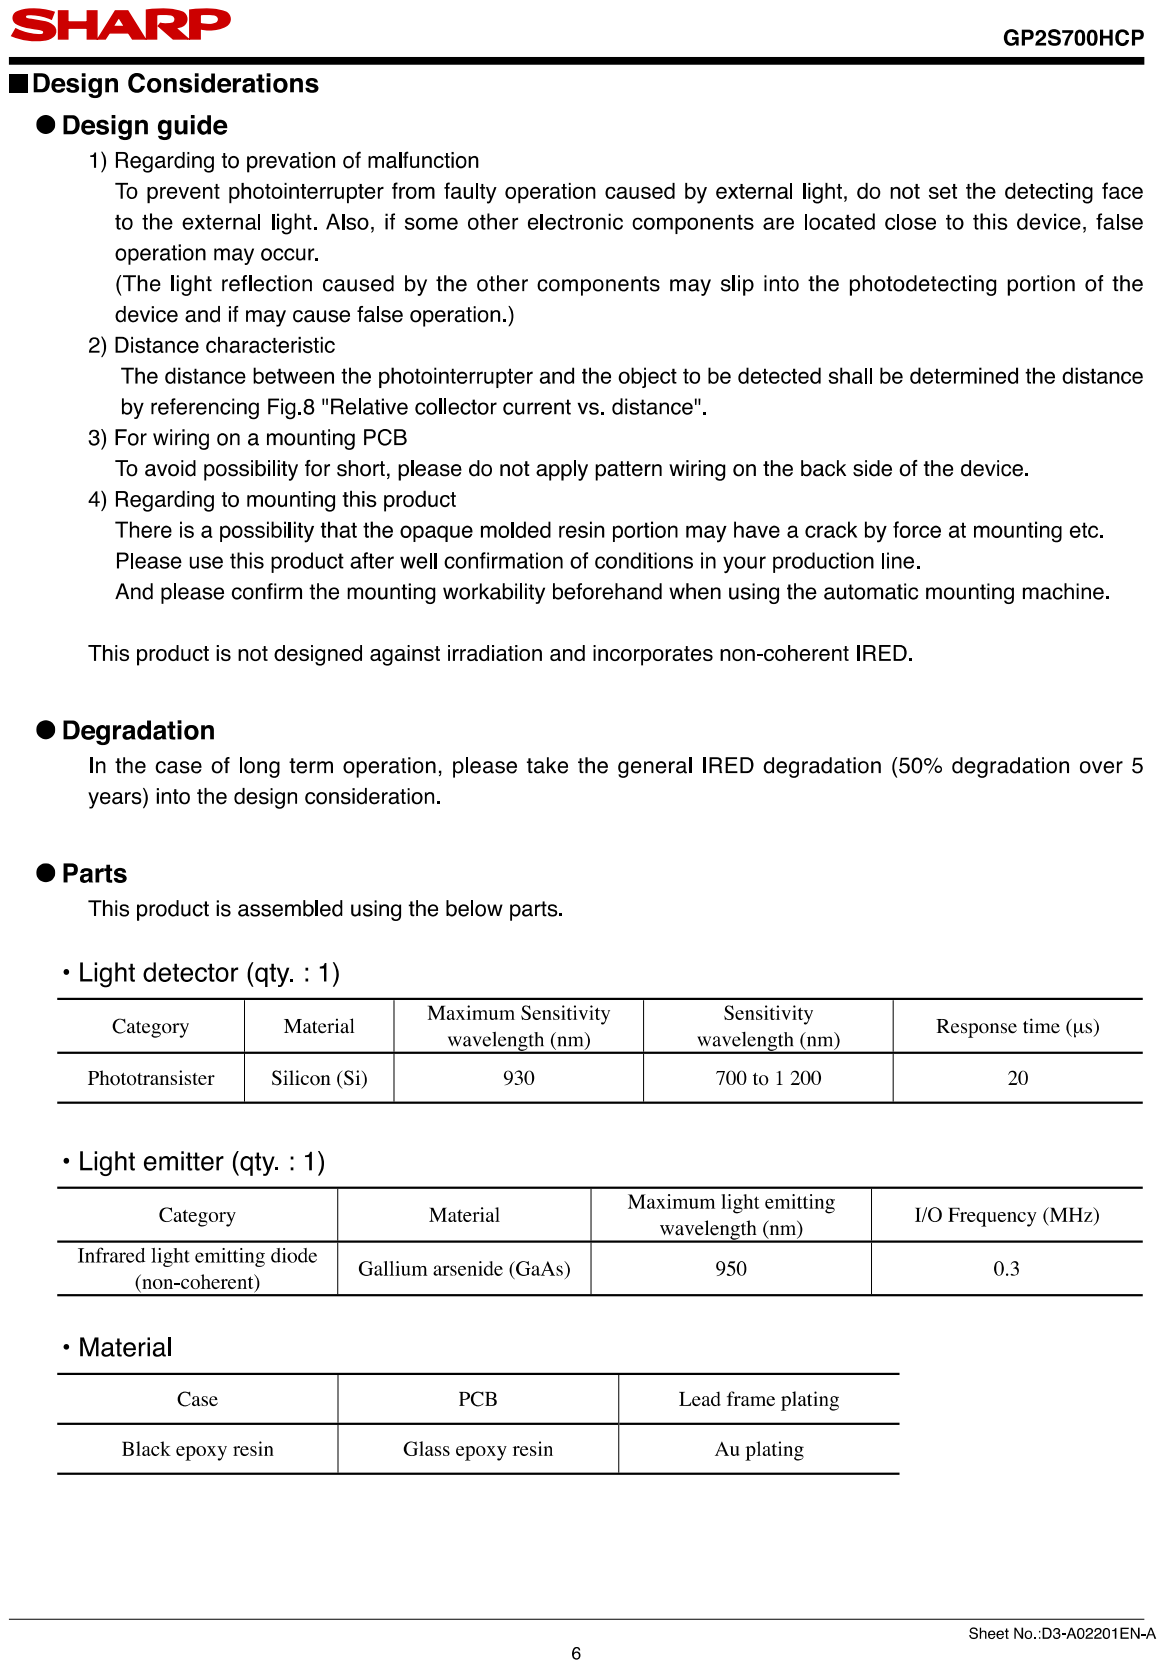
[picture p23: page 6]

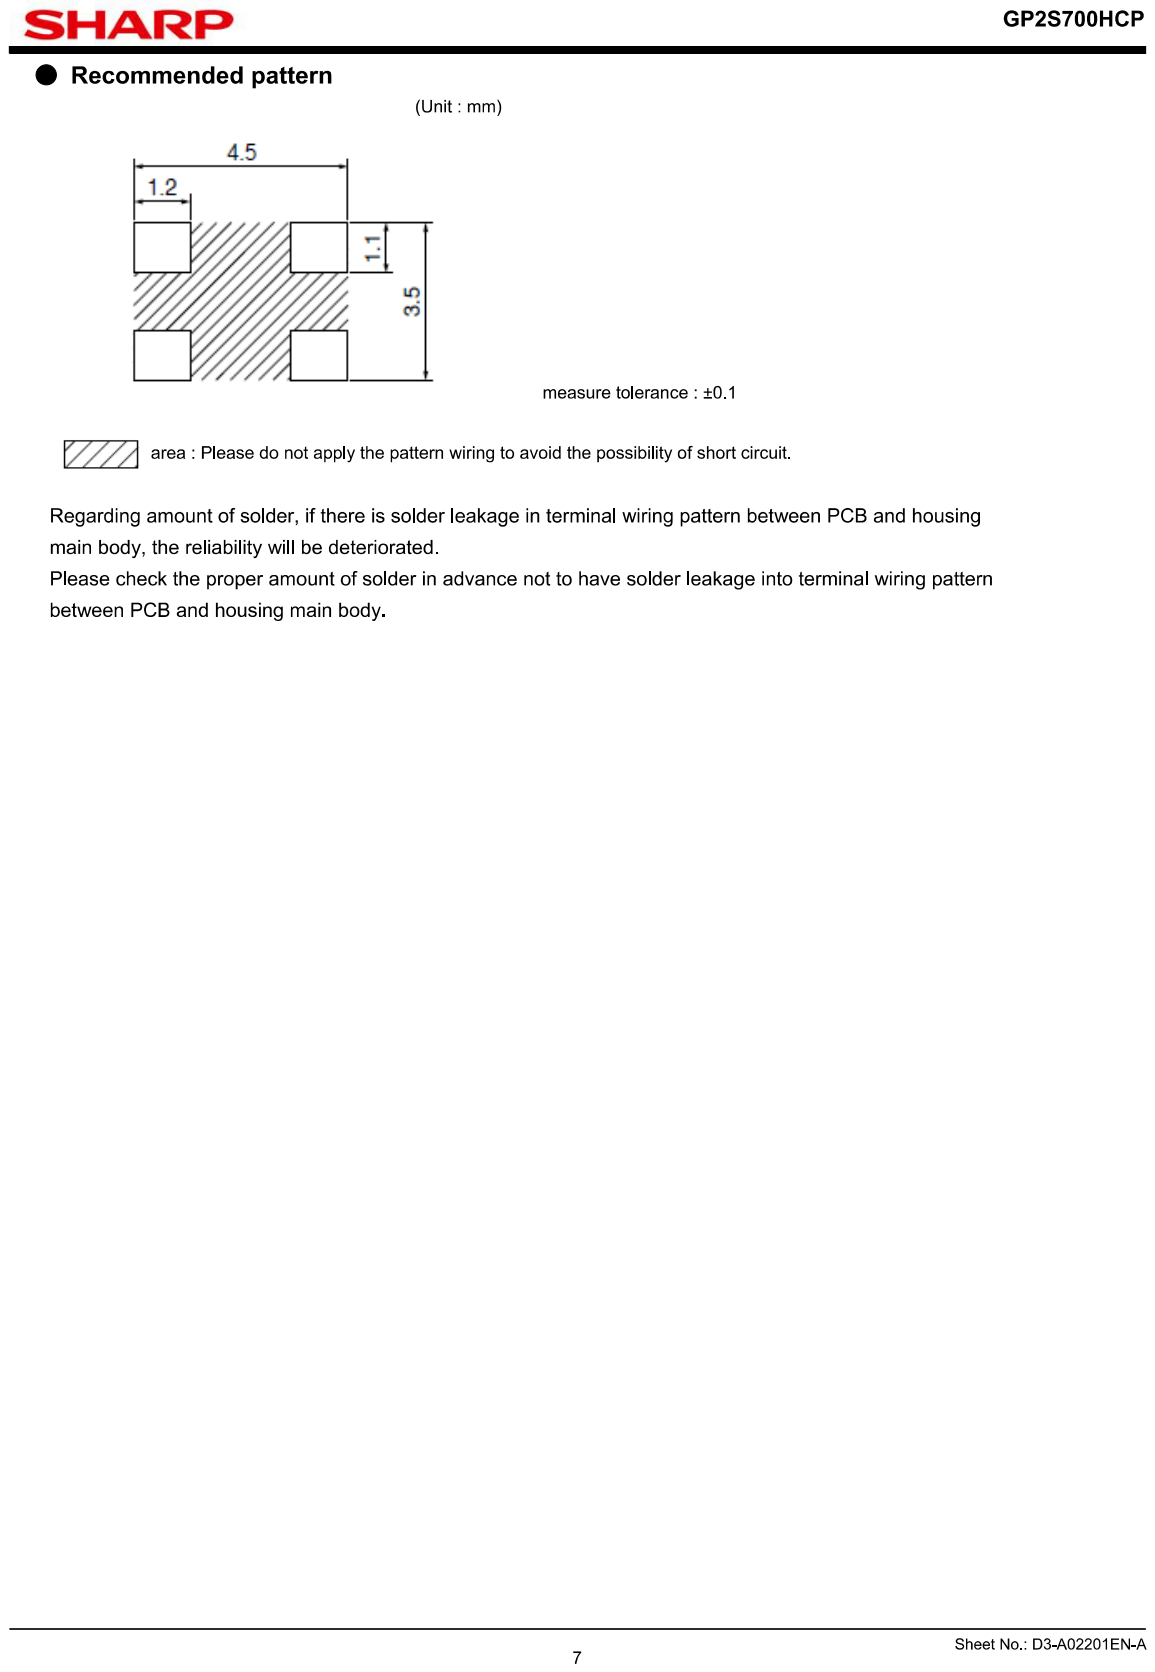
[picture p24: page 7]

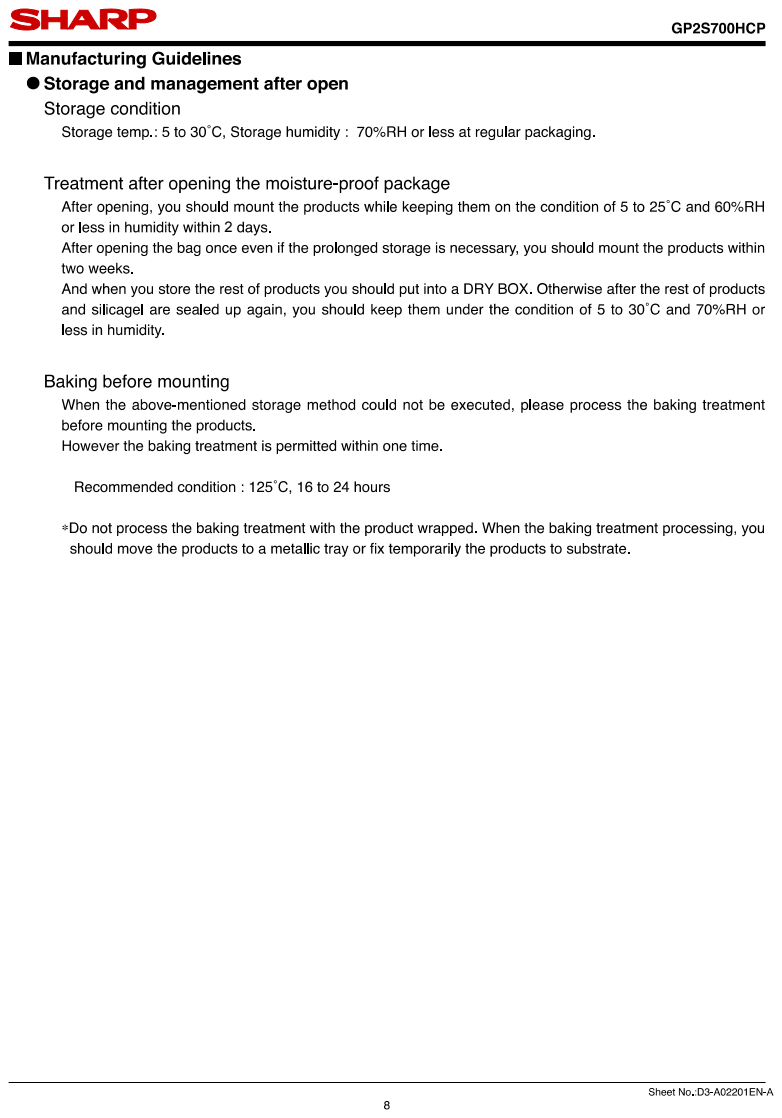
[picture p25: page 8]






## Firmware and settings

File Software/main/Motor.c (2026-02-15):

//###########################################################################
//
// FILE		: Motor.c
//
// TITLE	: Motor c file.
//
// Author	: Park Geon ju
//
// Company	: Maze & Hz
//
//###########################################################################
// $Release Date: 2017.07.22 $
//###########################################################################

#define   _MOTOR_


#include "DSP280x_Device.h"
#include "DSP280x_Examples.h"   // DSP280x Examples Include File
#include "Main.h"
#include "Motor.h"

//#define WHEEL_RADIUS			36.44
//#define Gear_Ratio 				3.35
//#define M_PI					3.141592653589

#define SAMPLE_FRQ				_IQ30( 0.0005 )			//500us

//PULSE_TO_D = (WHEEL_RADIUS * M_PI) / (encoder_pulse * 4) / geer_ratio 
//(24.5 * M_PI) / 4096 / 2.592592592592592
///#define PULSE_TO_D				_IQ30( 0.016484569660 )
//#define PULSE_TO_D				_IQ30( 0.01390444014 )
#define PULSE_TO_D				_IQ30( 0.007248059223 )

//PULSE_TO_V = (WHEEL_RADIUS * M_PI) / (encoder_pulse * 4) / geer_ratio / SAMPLE_FRQ
//(24.5 * M_PI) / 4096 / 2.592592592592592 / 0.0005
//#define PULSE_TO_V  			_IQ26( 32.96913932172 )
#define PULSE_TO_V  			_IQ25( 14.49611845 )
////////////////////////////////////////////       PID information       ///////////////////////////////////////////////////

// 9000으로 임의로 잡고 계산했을 경우 공회전으로 7700mm/s 정도까지 올라가는것 확인-> 정속 주행일때를 위해 좀 더 올려야 할 듯... 
#define MAX_PID_OUT				_IQ( 7700.0 )
#define MIN_PID_OUT				_IQ( -7700.0 )

//#define PWM_CONVERT				_IQ30( 0.2222222 )
#define PWM_CONVERT				_IQ30( 0.2597402597 )

/*extreme pd value*/
//#define	DOWN_KP  				_IQ7( 0.007 )  // 
#define	DOWN_KP  				_IQ17( 0.028 )
#define DOWN_KD					_IQ7( 0.005 )

//떨어 뜨릴 값이 0.1 까지 이므로 1.5에서 0.1의 차이는 1.3 이다.
//따라서 간 거리가 200이 될때까지 1.3을 떨어뜨려야 하므로 X * 200 = 1.3 이된다.  ?????


///////////////////////////////////////////        jerk control            /////////////////////////////////////////////////////

 //jerk time.
 //T = ( ( 60 * S / x ) ^ 1/3 ) s

 //x에 관한 식으로 고치면...
 //x = ( ( 60 * S ) / T^3 ) m/s^3

 //로봇에 사용하려면 mm/s^3으로 고쳐야 된다.( 거리가 mm단위를 사용하므로... )
 //x = ( ( 6 * S ) / ( 2.5 * ( 0.0005 )^2 ) ) mm/s^3
 //S는 한 인터럽트 당 거리 * qep value -> fp32tick_distance = int16qep_value * PULSE_TO_D;

 //모든 계산을 거치면 9600 * S 가 나오는데 가속도를 작은 값으로 쓰기 위해 시간이 us가 아니라 ms 이므로 9.6 * S 가 된다.

 //시작 할 때는 S가 0 이므로 최대 가속도 16일때의 거리 S = 1/2at^2 에 의해 0.5 * 16000 * ( 0.0005 )^2 = 0.0002 로 강제 처리.


#define JERK_VALUE			_IQ14(10000.0)
#define START_JERK_LIMIT	_IQ14(0.055555)

/////////////////////////////////////////////////////////////////////////////////////////////////////////////////////


void motor_vari_init( motor_vari_t *pm )
{
	memset( ( void * )pm , 0x00 , sizeof( motor_vari_t ) );

	pm->int32accel = 3500;

	pm->q28kp = g_q28kp;	//0.6	// 0.8 	//pm->q28kp = _IQ28( 0.62 );
	//pm->q28kp = _IQ28( 0.37 );
	pm->q28ki = _IQ28( 0 ); // 
	pm->q28kd = g_q28kd;  //0.65	//0.85 
	//pm->q17next_acc = _IQ17( 0 ) ;
}   

void diffvel_to_remaindist_cpt( volatile _iq17 cur_vel , volatile _iq17 tar_vel , volatile _iq17 acc , volatile _iq17 *decel_dist )
{
	/*
		현재속도와 최고속도를 기준으로 감속 거리를 구하는 함수
	*/

	cur_vel = _IQdiv( cur_vel , _IQ( 1000 ) ); 
	tar_vel = _IQdiv( tar_vel , _IQ( 1000 ) );
	acc = _IQdiv( acc , _IQ( 1000 ) );

	*decel_dist = _IQmpy( _IQdiv( _IQabs( _IQmpy( cur_vel , cur_vel ) - _IQmpy( tar_vel , tar_vel ) ) , ( acc << 1 ) ) , _IQ( 1000 ) );
}
	/*	
	g_q16left_handle_temp = _IQ16mpy(g_q16han_decstep, ( HANDLE_CENTER - ( g_pos.iq7pid_out << 9 )) ) + g_q16han_decmax;
	g_q16right_handle_temp = _IQ16mpy( g_q16han_accstep , ( HANDLE_CENTER + ( g_pos.iq7pid_out << 9 )) ) + g_q16han_accmax;
	*/

void handle_ad_make( volatile _iq16 acc_rate , volatile _iq16 dec_rate ) //handle 비율 갱신 함수 -> 포지션에 따른 턴속도 조절시 사용
{
	g_q16han_accstep = _IQ16div( ( _IQ16( 1 ) -  acc_rate ) , HANDLE_CENTER / 250 );	//0.6
	g_q16han_decstep = _IQ16div( ( dec_rate - _IQ16( 1 ) ) , HANDLE_CENTER / 250 );		//0.4

	g_q16han_accmax =( acc_rate );									//0.4
	g_q16han_decmax = ( _IQ16( 2.0 ) - dec_rate );									//1.5

}

//	decel_dist_compute( pinfo->q17in_vel, pinfo->q17out_vel, pinfo->q17acc, &pinfo->q17m_dist); [진입속도, 탈출속도, 가속도, ???]

void decel_dist_compute( volatile _iq17 cur_vel , volatile _iq17 tar_vel , volatile _iq17 acc , volatile _iq17 *decel_dist )
{
	/*
		현재속도와 최고속도를 기준으로 감속 거리를 구하는 함수
	*/
	
	cur_vel = _IQdiv( cur_vel , _IQ( 1000 ) );
	tar_vel = _IQdiv( tar_vel , _IQ( 1000 ) );
	acc = _IQdiv( acc , _IQ( 1000 ) );

	*decel_dist = _IQmpy( _IQdiv( _IQabs( _IQmpy( cur_vel , cur_vel ) - _IQmpy( tar_vel , tar_vel ) ) , ( acc << 1 ) ) , _IQ( 1000 ) );
	// s = // |v`^2 - v^2|/2a
}    //감속 거리 = |( 진입속도^2 - 탈출속도^2 )| / 2 * 가속도 

//max_vel_compute( _IQ17( pinfo->u16dist ), _IQ17(0.0), small_vel, pinfo->q17acc , &pinfo->q17vel ); 스타트 or 엔드 
//max_vel_compute( _IQ17( pinfo->u16dist ), pinfo->q17m_dist, big_vel, pinfo->q17acc, &pinfo->q17vel ); 나머지 

void max_vel_compute( volatile _iq17 dist , volatile _iq17 minus_dist , volatile _iq17 cur_vel , volatile _iq17 acc , volatile _iq17 *max_vel )
{ 	
	/*	
		거리값을 가지고 최고 속도를 구하는 함수 
		1000으로 나누는 것은 오버플로우를 막기 위해 처리하는 과정
		dist는 2로 한번 더 나누어야 하므로 2000으로 나눈다. 
	*/

	_iq17 curvel_2;
	_iq17 accdist;
	
	acc = _IQdiv( acc , _IQ( 1000 ) );
	dist = dist - minus_dist;
	dist = _IQdiv( dist , _IQ( 2000 ) );
	cur_vel =  _IQdiv( cur_vel , _IQ( 1000 ) );
	curvel_2 = _IQmpy( cur_vel , cur_vel );
	accdist = _IQmpy( _IQ17( 2.0 ) , _IQmpy( acc , dist ) ); // 2as

	*max_vel = _IQmpy(_IQ17sqrt(  ( curvel_2 + accdist ) ), _IQ17( 1000.0 )); //v` = root(v^2+2as)

	if( *max_vel >  g_q17fast_vel_limit )			*max_vel = g_q17fast_vel_limit; 	//최고 속도가 셋팅 속도보다 높으면 -> 셋팅 속도로 주행
	else if( *max_vel < g_q17user_vel )				*max_vel = g_q17user_vel;  			//최저 속도가 현재 턴 속도보다 낮으면 -> 턴속도로 주행
	else;
}

void Dist_to_minvel_cpt( volatile _iq17 dist , volatile _iq17 cur_vel , volatile _iq17 acc , volatile _iq17 *min_vel )
{
	_iq17 iq17acc = _IQ17( 0 );

	iq17acc = _IQ17( acc );

	dist = _IQ17div( dist, _IQ17( 1000 ) );
	cur_vel = _IQ17div( cur_vel, _IQ17( 1000 ) );

	*min_vel = _IQ17mpy(_IQ17sqrt(_IQ17mpy( cur_vel , cur_vel )- _IQ17mpy( iq17acc << 1 , dist ) ) ,_IQ7(1000));

	if( *min_vel < _IQ17(0.0) )
		*min_vel = _IQ17(0.0);
}

// 	dist거리만큼 vel속도로 이동한 후 acc가속도로 정지

void move_to_end( volatile _iq17 dist , volatile _iq17 vel , volatile _iq17 acc ) //end 라인아웃 시 사용 
{
	StopCpuTimer1();

	g_rm.int32accel = g_lm.int32accel = ( int32 )( acc >> 17 ); // 정지구간 가속도 변경.

	diffvel_to_remaindist_cpt( vel , _IQ( 0 ) , acc , &g_rm.q17decel_dist ); // 감속 거리 compute

	g_lm.q17decel_dist = g_rm.q17decel_dist;

	g_rm.q17user_dist = dist; // 명령 dist
	g_lm.q17user_dist = dist;
	
	g_rm.q17user_vel = vel; // 명령 vel
	g_lm.q17user_vel = vel;

	g_rm.q17err_dist = g_rm.q17user_dist - g_rm.q17total_dist;	// 남은 거리
	g_lm.q17err_dist = g_lm.q17user_dist - g_lm.q17total_dist;

	g_rm.q17decel_vel = _IQ( 0.0 );
	g_lm.q17decel_vel = _IQ( 0.0 );

	g_rm.u16decel_flag = ON;
	g_lm.u16decel_flag = ON;

	g_Flag.move_state = OFF;


	StartCpuTimer1();
	
}
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

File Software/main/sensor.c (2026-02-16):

//###########################################################################
//
// FILE		: Sensor.c
//
// TITLE		: Senser c file.
//
// Author	:  ?
//
// Company	: Maze & Hz
//
//###########################################################################
// $Release Date: 2016.07.19 $
//###########################################################################

#include "DSP280x_Device.h"
#include "DSP280x_Examples.h"   // DSP280x Examples Include File
#include "Main.h"
#include "Sensor.h"


#define POS_END _IQ7(4500) //14500


static position_enable(void);
static void   cross_check(void);


typedef volatile enum
{
	#if 1
	SEN0 = 11, //D6
	SEN1 = 12, //W0
	SEN2 = 13, //W1
	SEN3 = 6, //D1
	SEN4 = 7, //D2
	SEN5 = 8, //D3
	SEN6 = 9, //D4
	SEN7  = 10, //D5
	SEN_END = 15,
	ADC_NUM = 15
	#endif
	
}sensor_num;


volatile Uint16 sen_shoot_arr[ SEN_END ] = 
{
	SEN2, SEN1, SEN0, SEN3, SEN4, SEN5, SEN6, SEN7, 
    SEN3, SEN4, SEN5, SEN6, SEN7, SEN1, SEN2    
};


volatile Uint16 sen_adc_seq[ ADC_NUM ] = 
{
	ADC_1,ADC_0,ADC_7,ADC_2,ADC_3,ADC_4,ADC_5,ADC_6,
	ADC_10,ADC_11,ADC_12,ADC_13,ADC_14,ADC_8,ADC_9

};



volatile Uint16 state_table[] = 
{
	0xf000 , 0xf000 , 0xf000 , 
		
	0xf000 ,  // 1111 0000 0000 0000
	0x7800 ,  // 0111 1000 0000 0000
	0x3c00 ,  // 0011 1100 0000 0000
	0x1e00 ,  // 0001 1110 0000 0000	
	0x0f00 ,  // 0000 1111 0000 0000
	0x0780 ,  // 0000 0111 1000 0000
	0x03c0 ,  // 0000 0011 1100 0000
	0x01e0 ,  // 0000 0001 1110 0000	
	0x00f0 ,  // 0000 0000 1111 0000
	0x0078 ,  // 0000 0000 0111 1000
	0x003c ,  // 0000 0000 0011 1100
	0x001e ,  // 0000 0000 0001 1110
	0x000f ,  // 0000 0000 0000 1111
	
	0x000f , 0x000f , 0x000f
};



void sen_vari_init(void)
{
	//int16 sen_channel = 0;
	
	memset( ( void * )g_sen , 0x00 , sizeof( sen_t) * 16 );
	memset( ( void * )&g_pos, 0x00 , sizeof( position_t ) );
	memset( ( void * )&g_rmark, 0x00 , sizeof( turnmark_t ) );
	memset( ( void * )&g_lmark, 0x00 , sizeof( turnmark_t ) );

	g_pos.iq17kp = POS_KP_UP; 
	g_pos.iq17ki = _IQ17(0.0); 
	g_pos.iq17kd = POS_KD_UP;
	g_u16sen_enable = 0xffff;  

#if 0
	g_sen[ 15 ].iq7weight = _IQ7(16000);		g_sen[ 0 ].u16active_arr = 0x8000;		g_sen[ 0 ].u16passive_arr = 0x7fff;
	g_sen[ 14 ].iq7weight = _IQ7(14000);		g_sen[ 1 ].u16active_arr = 0x4000;		g_sen[ 1 ].u16passive_arr = 0xbfff;
	g_sen[ 13 ].iq7weight = _IQ7(12000);		g_sen[ 2 ].u16active_arr = 0x2000;		g_sen[ 2 ].u16passive_arr = 0xdfff;
	g_sen[ 12 ].iq7weight = _IQ7(10000);		g_sen[ 3 ].u16active_arr = 0x1000;		g_sen[ 3 ].u16passive_arr = 0xefff;	// 8900

	g_sen[ 11 ].iq7weight = _IQ7(8000);			g_sen[ 4 ].u16active_arr = 0x0800;		g_sen[ 4 ].u16passive_arr = 0xf7ff;	//7000
	g_sen[ 10 ].iq7weight = _IQ7(6500);			g_sen[ 5 ].u16active_arr = 0x0400;		g_sen[ 5 ].u16passive_arr = 0xfbff;	// 4000
	g_sen[ 9 ].iq7weight = _IQ7(3000);			g_sen[ 6 ].u16active_arr = 0x0200;		g_sen[ 6 ].u16passive_arr = 0xfdff;	// 1000
	g_sen[ 8 ].iq7weight = _IQ7(1000);			g_sen[ 7].u16active_arr = 0x0100;		g_sen[ 7 ].u16passive_arr = 0xfeff;	// 500

	g_sen[ 7 ].iq7weight = _IQ7(-1000);			g_sen[ 8 ].u16active_arr = 0x0080;		g_sen[ 8 ].u16passive_arr = 0xff7f;
	g_sen[ 6 ].iq7weight = _IQ7(-3000);			g_sen[ 9 ].u16active_arr = 0x0040;		g_sen[ 9 ].u16passive_arr = 0xffbf;
	g_sen[ 5 ].iq7weight = _IQ7(-6500);			g_sen[ 10].u16active_arr = 0x0020;		g_sen[ 10 ].u16passive_arr = 0xffdf;
	g_sen[ 4 ].iq7weight = _IQ7(-8000);			g_sen[ 11].u16active_arr = 0x0010;		g_sen[ 11 ].u16passive_arr = 0xffef;

	g_sen[ 3 ].iq7weight = _IQ7(-10000);		g_sen[ 12 ].u16active_arr = 0x0008;		g_sen[ 12 ].u16passive_arr = 0xfff7;
	g_sen[ 2 ].iq7weight = _IQ7(-12000);		g_sen[ 13].u16active_arr = 0x0004;		g_sen[ 13 ].u16passive_arr = 0xfffb;
	g_sen[ 1 ].iq7weight = _IQ7(-14000);		g_sen[ 14 ].u16active_arr = 0x0002;		g_sen[ 14 ].u16passive_arr = 0xfffd;
	g_sen[ 0 ].iq7weight = _IQ7(-16000);		g_sen[ 15 ].u16active_arr = 0x0001;		g_sen[ 15 ].u16passive_arr = 0xfffe;
#endif


#if 1
	g_sen[ 15 ].iq7weight = _IQ7(14500);		g_sen[ 15 ].u16active_arr = 0x8000; 	g_sen[ 15 ].u16passive_arr = 0xffff;
 	g_sen[ 14 ].iq7weight = _IQ7(12500);		g_sen[ 14 ].u16active_arr = 0x4000; 	g_sen[ 14 ].u16passive_arr = 0xbfff;
    
	g_sen[ 13 ].iq7weight = _IQ7(10500);		g_sen[ 13 ].u16active_arr = 0x2000; 	g_sen[ 13 ].u16passive_arr = 0xdfff;
	g_sen[ 12 ].iq7weight = _IQ7(4500);			g_sen[ 12 ].u16active_arr = 0x1000; 	g_sen[ 12 ].u16passive_arr = 0xefff;	// 8900

	g_sen[ 11 ].iq7weight = _IQ7(3200); 		g_sen[ 11 ].u16active_arr = 0x0800; 	g_sen[ 11 ].u16passive_arr = 0xf7ff;	//7000
	g_sen[ 10 ].iq7weight = _IQ7(2100); 		g_sen[ 10 ].u16active_arr = 0x0400; 	g_sen[ 10 ].u16passive_arr = 0xfbff;	// 4000
	g_sen[ 9 ].iq7weight = _IQ7(1100);			g_sen[ 9 ].u16active_arr = 0x0200;		g_sen[ 9 ].u16passive_arr = 0xfdff; 	// 1000
	g_sen[ 8 ].iq7weight = _IQ7(300);			g_sen[ 8 ].u16active_arr = 0x0100;		g_sen[ 8 ].u16passive_arr = 0xfeff; 	// 500

	g_sen[ 7 ].iq7weight = _IQ7(-300); 		    g_sen[ 7 ].u16active_arr = 0x0080;		g_sen[ 7 ].u16passive_arr = 0xff7f;
	g_sen[ 6 ].iq7weight = _IQ7(-1100); 		g_sen[ 6 ].u16active_arr = 0x0040;		g_sen[ 6 ].u16passive_arr = 0xffbf;
	g_sen[ 5 ].iq7weight = _IQ7(-2100); 		g_sen[ 5 ].u16active_arr = 0x0020;		g_sen[ 5 ].u16passive_arr = 0xffdf;
	g_sen[ 4 ].iq7weight = _IQ7(-3200); 		g_sen[ 4 ].u16active_arr = 0x0010;		g_sen[ 4 ].u16passive_arr = 0xffef;

	g_sen[ 3 ].iq7weight = _IQ7(-4500);		    g_sen[ 3 ].u16active_arr = 0x0008;		g_sen[ 3 ].u16passive_arr = 0xfff7;
	g_sen[ 2 ].iq7weight = _IQ7(-10500);		g_sen[ 2 ].u16active_arr = 0x0004;		g_sen[ 2 ].u16passive_arr = 0xfffb;
	g_sen[ 1 ].iq7weight = _IQ7(-12500);		g_sen[ 1 ].u16active_arr = 0x0002;		g_sen[ 1 ].u16passive_arr = 0xfffd;
	g_sen[ 0 ].iq7weight = _IQ7(-14500);		g_sen[ 0 ].u16active_arr = 0x0001;		g_sen[ 0 ].u16passive_arr = 0xfffe;    

#endif
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

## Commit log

2026-01-08 gyro init
    [DSP280x_Adc.obj, DSP280x_CodeStartBranch.obj, DSP280x_CpuTimers.obj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]
2026-01-08 rom error
    [DSP280x_Adc.obj, DSP280x_CodeStartBranch.obj, DSP280x_CpuTimers.obj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]
2026-01-10 rom bug clear & sensor set
    [DSP280x_Adc.obj, DSP280x_CodeStartBranch.obj, DSP280x_CpuTimers.obj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]
2026-01-15 0115 fastrun
    [DSP280x_Adc.obj, DSP280x_CodeStartBranch.obj, DSP280x_CpuTimers.obj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]
2026-01-27 3rd start
    [DSP280x_Adc.obj, DSP280x_CodeStartBranch.obj, DSP280x_CpuTimers.obj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]
2026-02-15 3rd end
    [DSP280x_Adc.obj, DSP280x_CodeStartBranch.obj, DSP280x_CpuTimers.obj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]
2026-02-17 map done
    [DSP280x_Adc.obj, DSP280x_CodeStartBranch.obj, DSP280x_CpuTimers.obj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]
2026-03-30 move files
    [DSP280x_Adc.obj, DSP280x_CodeStartBranch.obj, DSP280x_CpuTimers.obj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]
2026-03-30 add folder
    [GEAR.STEP, JP_MTG_L.STEP, JP_MTG_R.STEP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]
